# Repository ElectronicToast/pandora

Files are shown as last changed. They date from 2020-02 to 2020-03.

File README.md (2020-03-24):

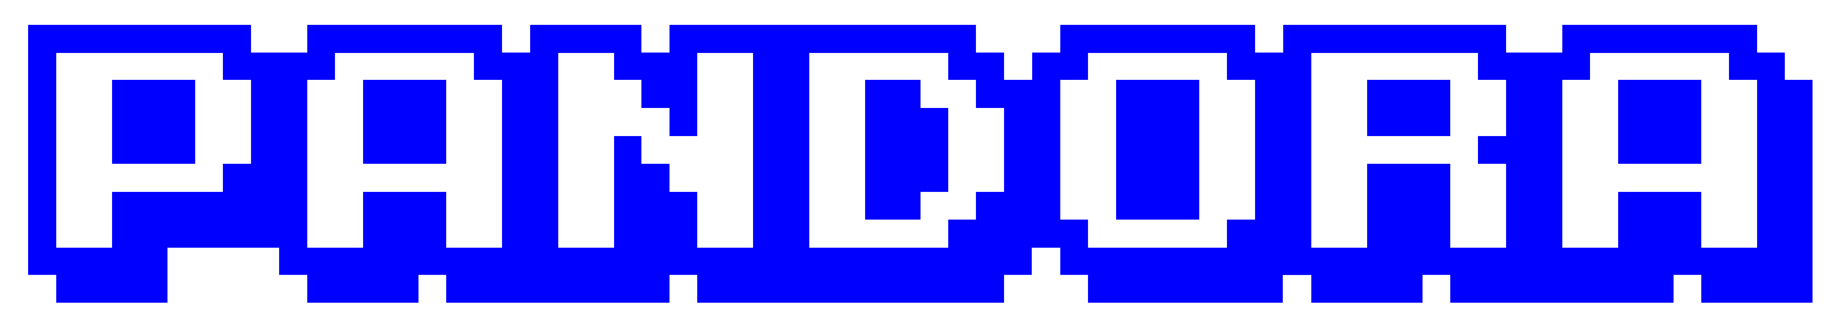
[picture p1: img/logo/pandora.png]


  

TI SimpleLink CC2652R mesh network embedded system development board

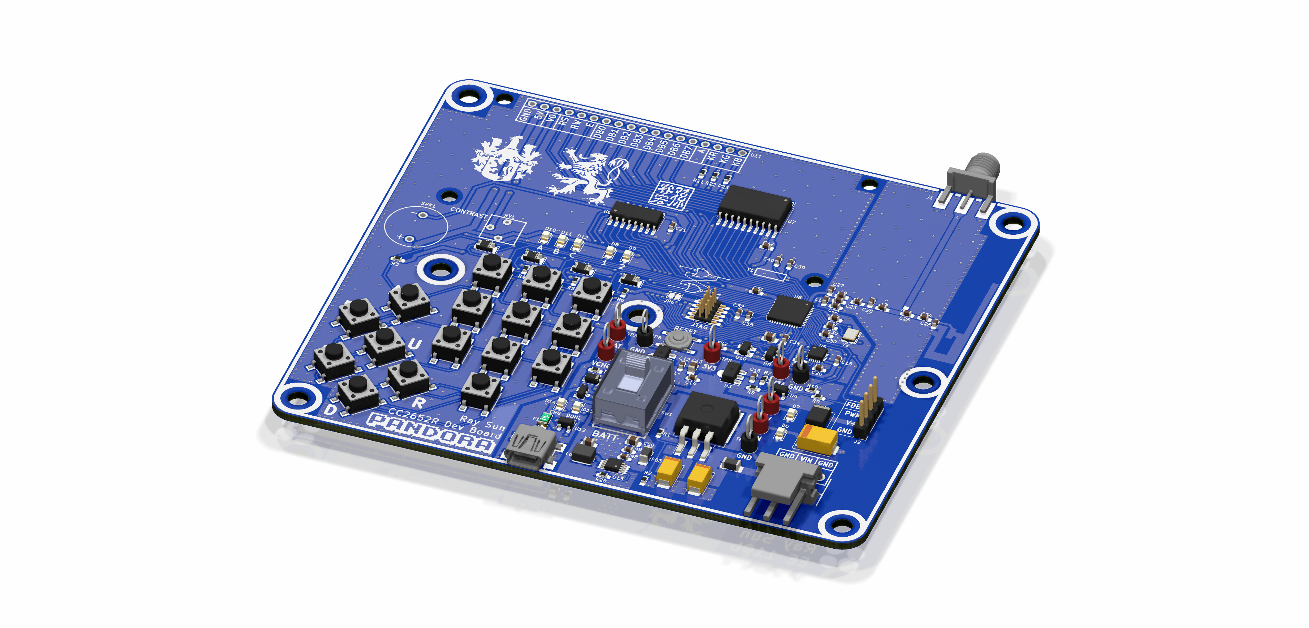
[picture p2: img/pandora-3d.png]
board-3d


## Description
Pandora is a development board for the TI SimpleLink CC2652R multiprotocol dual-core ARM wireless MCU designed for the Embedded System Design Laboratory course at Caltech (EE 110b). The board features interfaces for connecting a servo with analog feedback output and a [16x2 RGB-backlit LCD](https://www.adafruit.com/product/399). An onboard 16-key keypad and MPU-9250 IMU are provided for development use.

Pandora is intended to be powered from either an external 6-8.2V supply or a single-cell 3.7V LiPo battery. The former must be used to power the servo. A slide switch is used to select the power source. An onboard LiPo charger is present for charging through the USB-mini jack.

A TI SWRU120D 2.4GHz inverted-F PCB antenna is provided, in addition to a SMA jack for connecting an external 2.4GHz antenna. The antenna is selected using an 0603 two-way jumper.

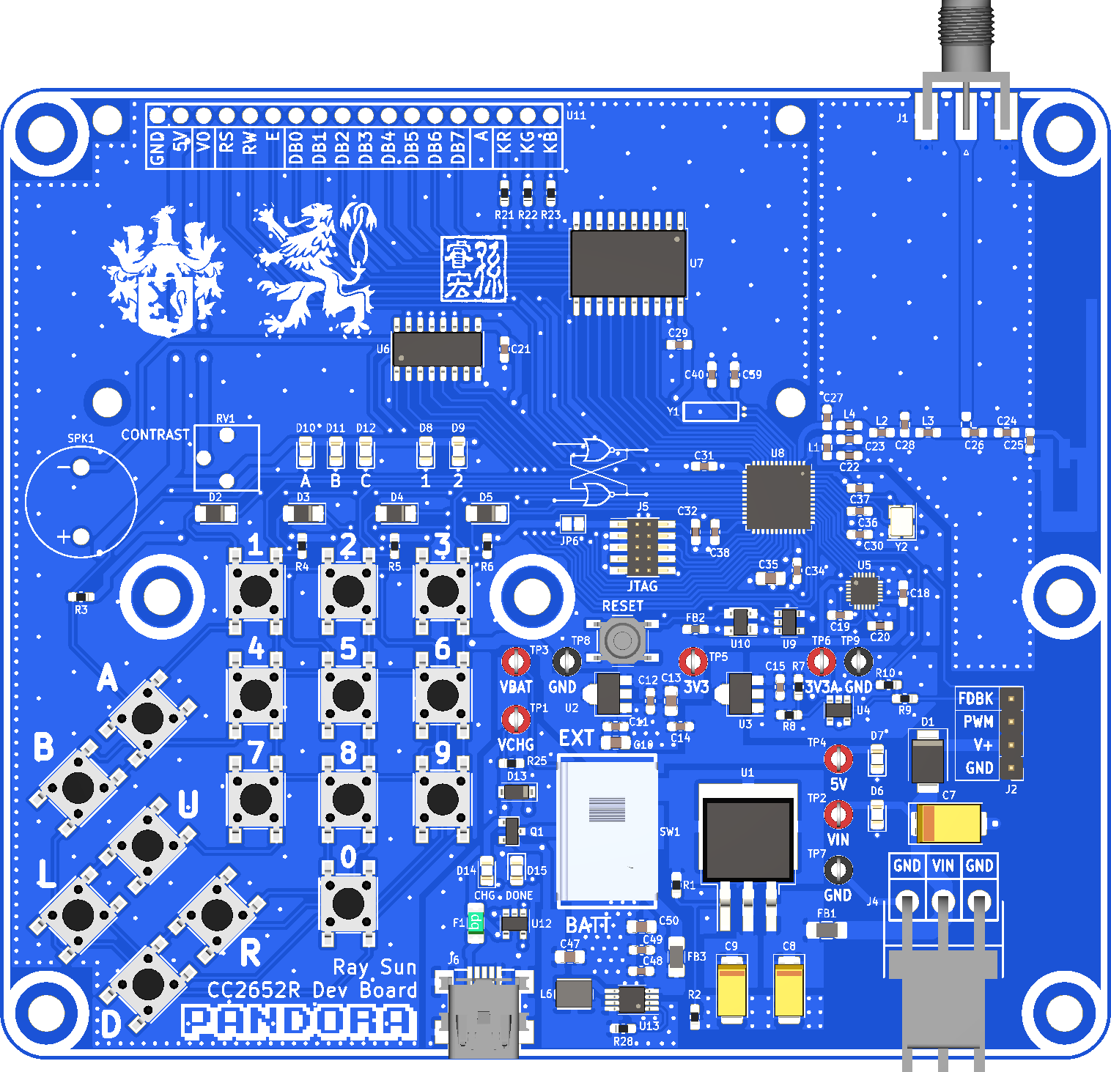
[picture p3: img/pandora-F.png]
board-f

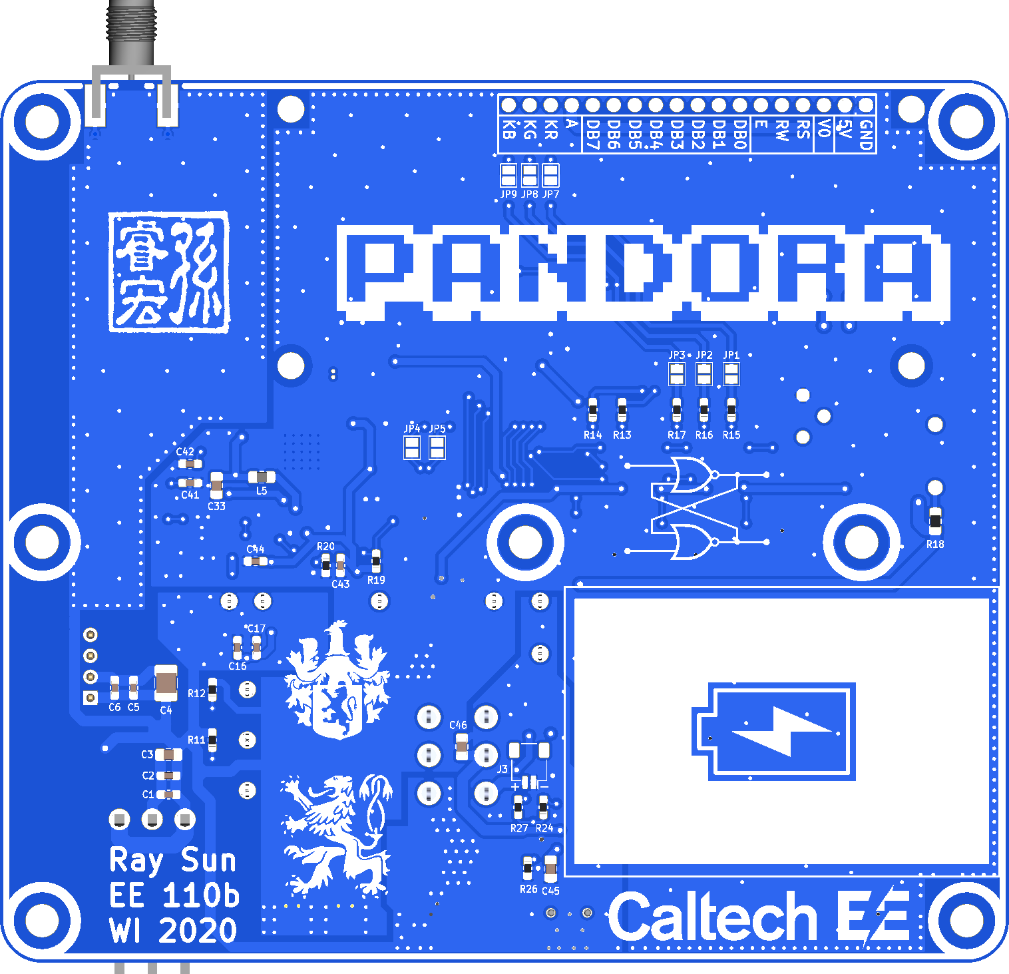
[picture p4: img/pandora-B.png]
board-b


This PCB is designed with KiCad v.5.1.5. Documentation may be found under `/doc`, and Gerbers under `/gerber`. 

## Author
- Ray Sun - Undergraduate, Electrical Engineering, Caltech, Class of 2020

## Licensing
This project is released under the terms of the MIT License. The SWRU120D antenna design is copyright 2007–2019, Texas Instruments Incorporated, and is used here for development of an application that uses a TI SimpleLink wireless microcontroller.

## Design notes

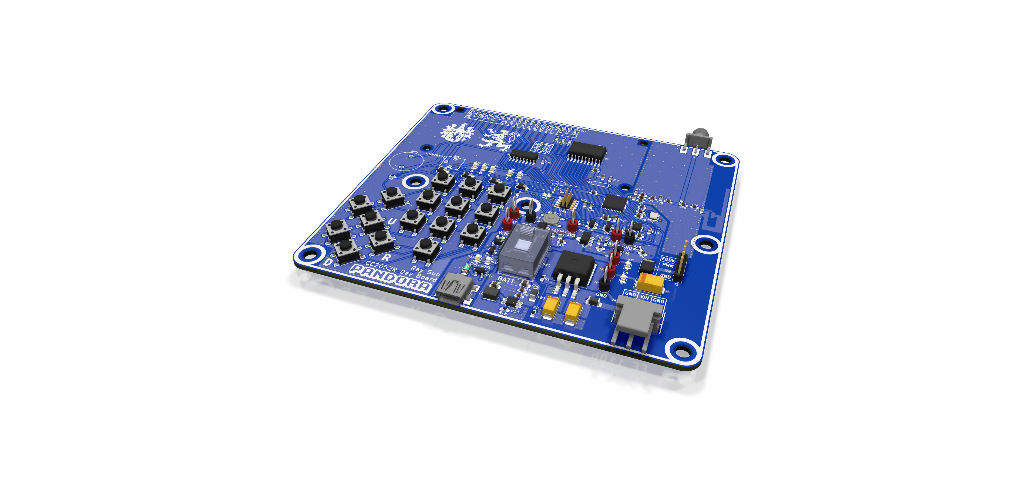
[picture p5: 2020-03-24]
img/pandora-3d-proj.png

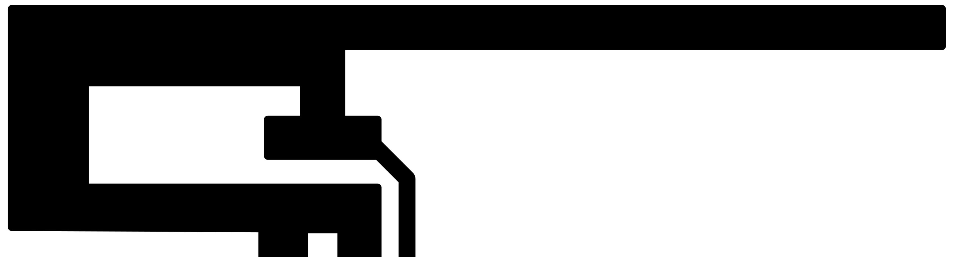
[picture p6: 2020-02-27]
img/footprints/SWRU120D.png

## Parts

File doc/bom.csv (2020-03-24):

Designator | Value | FootprintRef | Datasheet | Comment | Footprint | PartNo | Supplier | SupplierPartNo | Qty
AE1 | SWRU120D | pandora:Texas_SWRU120D_InvF_2.4GHz_Left | http://www.ti.com/lit/an/swru120d/swru120d.pdf | PCB antenna | SWRU120D | N/A | N/A | N/A | 1
> C1, C6, C16, C19-C21, C29-C32, C34, C36, C37, C43, C44, C48 | 0.1uF | Capacitor_SMD:C_0603_1608Metric_Pad1.05x0.95mm_HandSolder | ~ |  | 603 |  | In House | N/A | 16
C4 | 47uF | Capacitor_SMD:C_1210_3225Metric_Pad1.42x2.65mm_HandSolder | ~ |  | 805 |  | In House | N/A | 1
C7 | 47uF | Capacitor_Tantalum_SMD:CP_EIA-7343-31_Kemet-D | https://content.kemet.com/datasheets/KEM_T2005_T491.pdf | 25V | 2917 | T491D476M025AT | Digi-Key | 399-3797-1-ND | 1
> C8, C9 | 10uF | Capacitor_Tantalum_SMD:CP_EIA-6032-28_Kemet-C_Pad2.25x2.35mm_HandSolder | http://datasheets.avx.com/trj.pdf | 35V | 2312 | TRJC106K035R0600 | Digi-Key | 478-7582-1-ND | 2
> C10, C33, C35 | 22uF | Capacitor_SMD:C_0805_2012Metric_Pad1.15x1.40mm_HandSolder | ~ |  | 805 |  | In House | N/A | 3
> C2, C5, C11, C12, C14, C15, C17, C38, C49 | 1uF | Capacitor_SMD:C_0603_1608Metric_Pad1.05x0.95mm_HandSolder | ~ |  | 603 |  | In House | N/A | 9
> C3, C13, C50 | 10uF | Capacitor_SMD:C_0805_2012Metric_Pad1.15x1.40mm_HandSolder | ~ |  | 805 |  | In House | N/A | 3
C18 | 10nF | Capacitor_SMD:C_0603_1608Metric_Pad1.05x0.95mm_HandSolder | ~ |  | 603 |  | In House | N/A | 1
C22 | 12pF | pandora:0603 | ~ |  | 603 |  | In House | N/A | 1
C24 | 1.8pF | pandora:0603 | ~ |  | 603 |  | In House | N/A | 1
C25 | DNP | pandora:0603 | ~ |  | 603 |  | In House | N/A | 1
C26 | 12pF | pandora:0603_Branch | ~ |  | 0603-2way |  | In House | N/A | 1
> C23, C27, C28 | 1pF | pandora:0603 | ~ |  | 603 |  | In House | N/A | 3
> C39, C40 | 15pF | Capacitor_SMD:C_0603_1608Metric_Pad1.05x0.95mm_HandSolder | ~ |  | 603 |  | In House | N/A | 2
> C41, C42 | 12pF | Capacitor_SMD:C_0603_1608Metric_Pad1.05x0.95mm_HandSolder | ~ |  | 603 |  | In House | N/A | 2
> C45-C47 | 4.7uF | Capacitor_SMD:C_0805_2012Metric_Pad1.15x1.40mm_HandSolder | ~ |  | 805 |  | In House | N/A | 3
D1 | S3JBHR5G | Diode_SMD:D_SMB | https://www.onsemi.com/pub/Collateral/1N5400-D.PDF | 3A | SMB | S3JBHR5G | Digi-Key | S3JBHR5GCT-ND | 1
> D2-D5 | 1N4148 | Diode_SMD:D_1206_3216Metric_Pad1.42x1.75mm_HandSolder | https://www.diodes.com/assets/Datasheets/ds30086.pdf |  | 1206 / SOD-123 |  | In House | N/A | 4
> D6, D10 | RED | LED_SMD:LED_0805_2012Metric_Pad1.15x1.40mm_HandSolder | ~ |  | 805 |  | In House | N/A | 2
> D7, D11, D15 | GREEN | LED_SMD:LED_0805_2012Metric_Pad1.15x1.40mm_HandSolder | ~ |  | 805 |  | In House | N/A | 3
> D8, D9, D12 | BLUE | LED_SMD:LED_0805_2012Metric_Pad1.15x1.40mm_HandSolder | ~ |  | 805 |  | In House | N/A | 3
D13 | PMEG10020ELRX | pandora:D_SOD-123W | https://assets.nexperia.com/documents/data-sheet/PMEG10020ELR.pdf |  | SOD-123W | PMEG10020ELRX | Digi-Key | 1727-2396-1-ND | 1
D14 | ORANGE | LED_SMD:LED_0805_2012Metric_Pad1.15x1.40mm_HandSolder | ~ |  | 805 |  | In House | N/A | 1
F1 | 0ZCJ0075FF2E | Fuse:Fuse_1206_3216Metric_Pad1.42x1.75mm_HandSolder | https://www.belfuse.com/resources/datasheets/circuitprotection/ds-cp-0zcj-series.pdf | Charging input fuse, 750mA hold | 1206 | 0ZCJ0075FF2E | Digi-Key | 507-1804-1-ND | 1
> FB1, FB3 | 1206_4A | Inductor_SMD:L_1206_3216Metric_Pad1.42x1.75mm_HandSolder | https://ds.yuden.co.jp/TYCOMPAS/ut/detail?pn=BKP2125HS600-T%20%20&u=M |  | 1206 | FBMJ3216HS800-T | Digi-Key | 587-1772-1-ND | 2
FB2 | 0603_500mA | Inductor_SMD:L_0603_1608Metric_Pad1.05x0.95mm_HandSolder | https://ds.yuden.co.jp/TYCOMPAS/ut/detail?pn=BKP1608HS391-T%20%20&u=M |  | 603 | BKP1608HS391-T | Digi-Key | 587-1927-1-ND | 1
> H1-H7 | #6 | pandora:MountingHole_No6 | ~ | #6 mounting hole, NPTH | HOLE_156mil_NPTH | N/A | N/A | N/A | 7
J1 | SMA | Connector_Coaxial:SMA_Molex_73251-1153_EdgeMount_Horizontal | https://www.molex.com/pdm_docs/sd/732511153_sd.pdf | External antenna connector | SMA_SMD_RightAngle | 732511150 | Molex | 732511150 | 1
J2 | PinHeader_100mil_01x04 | Connector_PinHeader_2.54mm:PinHeader_1x04_P2.54mm_Vertical | ~ | Servo connector | 100mil_01x04 |  | In House | N/A | 1
J3 | JST-SH_2 | Connector_JST:JST_SH_SM02B-SRSS-TB_1x02-1MP_P1.00mm_Horizontal | ~ | JST SH auxiliary Li-ion connector | JST-SH_SM_2_SMD_RghtAngle |  | In House | N/A | 1
J4 | TX3 / MTA-156-3 | pandora:TE_640389-3 | ~ | 156mil 3-pin power connector | 156mil_01x03 |  | In House | N/A | 1
J5 | Conn_ARM_JTAG_SWD_10 | pandora:PinHeader_2x05_P1.27mm_Vertical_SMD_Long | http://infocenter.arm.com/help/topic/com.arm.doc.ddi0314h/DDI0314H_coresight_components_trm.pdf | JTAG debug header | 50mil_02x05 | FTSH-105-0.1-F-DV-K | In House | N/A | 1
J6 | USB_B_Mini | pandora:USB_MiniB_KMBSMT5SS30 | ~ | 5V battery charge connector | KMBSMT5SS30 | KMBSMT5SS30 | In House | N/A | 1
> JP1-JP5, JP7-JP9 | SJ2 | Jumper:SolderJumper-2_P1.3mm_Open_Pad1.0x1.5mm | ~ | Solder jumper, 2 pad | SMD_PAD_SJ2 | N/A | N/A | N/A | 8
JP6 | SJ2_Bridged | Jumper:SolderJumper-2_P1.3mm_Bridged_Pad1.0x1.5mm | ~ | Solder jumper, 2 pad, bridged | SMD_PAD_SJ2_Bridged | N/A | N/A | N/A | 1
> L2, L3 | 2nH | pandora:0603 | ~ |  | 603 |  | In House | N/A | 2
> L1, L4 | 2.4nH | pandora:0603 | ~ |  | 603 |  | In House | N/A | 2
L5 | 6.8uH | Inductor_SMD:L_0805_2012Metric_Pad1.15x1.40mm_HandSolder | https://product.tdk.com/info/en/catalog/datasheets/inductor_automotive_decoupling_mlz2012_en.pdf | MCU analog filter inductor | 805 | MLZ2012N6R8LTD25 | Digi-Key | 445-16384-1-ND | 1
L6 | 4.7uH | Inductor_SMD:L_Wuerth_MAPI-4020 | https://www.we-online.com/catalog/datasheet/74438356047.pdf | Power inductor for boost converter | Wuerth_MAPI-4020 | 74438356047 | Digi-Key | 732-8234-1-ND | 1
> NT1-NT5 | Net-Tie_2 | pandora:NetTie-2_SMD_50mil | ~ |  | N/A | N/A | N/A | N/A | 5
Q1 | DMP1045U | Package_TO_SOT_SMD:SOT-23 | https://www.diodes.com/assets/Datasheets/DMP1045U.pdf | Load sharing P-MOSFET | SOT-23 | DMP1045U-7 | Digi-Key | DMP1045U-7DICT-ND | 1
> R1, R12 | 1.2k | Resistor_SMD:R_0603_1608Metric_Pad1.05x0.95mm_HandSolder | ~ |  | 603 |  | In House | N/A | 2
R2 | 3.6k | Resistor_SMD:R_0603_1608Metric_Pad1.05x0.95mm_HandSolder | ~ |  | 603 |  | In House | N/A | 1
> R3-R6, R19, R25, R26, R28 | 10k | Resistor_SMD:R_0603_1608Metric_Pad1.05x0.95mm_HandSolder | ~ |  | 603 |  | In House | N/A | 8
R8 | 160k | Resistor_SMD:R_0603_1608Metric_Pad1.05x0.95mm_HandSolder | ~ |  | 603 |  | In House | N/A | 1
> R7, R9 | 150k | Resistor_SMD:R_0603_1608Metric_Pad1.05x0.95mm_HandSolder | ~ |  | 603 |  | In House | N/A | 2
R10 | 120k | Resistor_SMD:R_0603_1608Metric_Pad1.05x0.95mm_HandSolder | ~ |  | 603 |  | In House | N/A | 1
R11 | 3.3k | Resistor_SMD:R_0603_1608Metric_Pad1.05x0.95mm_HandSolder | ~ |  | 603 |  | In House | N/A | 1
R13 | 330 | Resistor_SMD:R_0603_1608Metric_Pad1.05x0.95mm_HandSolder | ~ |  | 603 |  | In House | N/A | 1
> R14, R17 | 390 | Resistor_SMD:R_0603_1608Metric_Pad1.05x0.95mm_HandSolder | ~ |  | 603 |  | In House | N/A | 2
R15 | 680 | Resistor_SMD:R_0603_1608Metric_Pad1.05x0.95mm_HandSolder | ~ |  | 603 |  | In House | N/A | 1
R16 | 560 | Resistor_SMD:R_0603_1608Metric_Pad1.05x0.95mm_HandSolder | ~ |  | 603 |  | In House | N/A | 1
R18 | 10 | Resistor_SMD:R_0805_2012Metric_Pad1.15x1.40mm_HandSolder | ~ | Speaker power resistor | 805 |  | In House | N/A | 1
R20 | 100k | Resistor_SMD:R_0603_1608Metric_Pad1.05x0.95mm_HandSolder | ~ |  | 603 |  | In House | N/A | 1
> R21-R23 | 0 | Resistor_SMD:R_0603_1608Metric_Pad1.05x0.95mm_HandSolder | ~ |  | 603 |  | In House | N/A | 3
> R24, R27 | 1k | Resistor_SMD:R_0603_1608Metric_Pad1.05x0.95mm_HandSolder | ~ |  | 603 |  | In House | N/A | 2
RV1 | 10k | pandora:Pot_VR4_Small | https://www.bourns.com/docs/Product-Datasheets/TC33.pdf | LCD contrast potentiometer | Bourns_TC33 | TC33X-2-103E | Digi-Key | TC33X-103ECT-ND | 1
SPK1 | DBX-01PN | pandora:DBX-01PN | ~ | Speaker, board mount | DBX-01PN | DBX-01PN | In House | DBX-01PN | 1
SW1 | GF-126-0317 | pandora:GF-126-0317 | https://media.digikey.com/pdf/Data%20Sheets/CW%20Industries%20PDFs/GF-126-0317.pdf | Power switch | GF-126-037 | GF-126-037 | Digi-Key | CWI351-ND | 1
> SW2-SW8, SW10-SW12 | PTS645-S-H-50-SMTR92-LFS | pandora:SW_Push_PTS645_SMT | https://dznh3ojzb2azq.cloudfront.net/products/Tactile/PTS645/documents/datasheet.pdf | Keypad button, black | Tact_Push_SMD_6mm | PTS645SH50SMTR92 LFS | Digi-Key | CKN9085CT-ND | 10
> SW9, SW13 | PTS645-S-M-43-SMTR92-LFS | pandora:SW_Push_PTS645_SMT | https://dznh3ojzb2azq.cloudfront.net/products/Tactile/PTS645/documents/datasheet.pdf | Keypad button, blue | Tact_Push_SMD_6mm | PTS645SM43SMTR92 LFS | Digi-Key | CKN9112CT-ND | 2
> SW14-SW17 | PTS645-S-K-50-SMTR92-LFS | pandora:SW_Push_PTS645_SMT | https://dznh3ojzb2azq.cloudfront.net/products/Tactile/PTS645/documents/datasheet.pdf | Keypad button, red | Tact_Push_SMD_6mm | PTS645SK50SMTR92 LFS | Digi-Key | CKN9087CT-ND | 4
SW18 | PTS526-S-K-15-SMTR92 | pandora:SW_Push_PTS526 | https://dznh3ojzb2azq.cloudfront.net/products/Tactile/PTS526/documents/datasheet.pdf | Reset button | Tact_Push_SMD_PTS526 | PTS526SK15SMTR92 LFS | In House | PTS526SK15SMTR92 LFS | 1
> TP1-TP9 | TestPoint | pandora:TestPoint_62-80mil | ~ | Test point | Hole_62mil | TP | In House | TP | 9
U1 | LM1086CS-ADJ | Package_TO_SOT_SMD:TO-263-3_TabPin2 | http://www.ti.com/lit/ds/snvs039j/snvs039j.pdf | 5V LDO | TO-263 | LM1086CS-ADJ | In House | LM1086CS-ADJ | 1
> U2, U3 | MCP1702T-3302 | Package_TO_SOT_SMD:SOT-89-3 | http://ww1.microchip.com/downloads/en/devicedoc/22008e.pdf | ... | SOT-89-3 | MCP1702T-3302 | In House | MCP1702T-3302 | 2
U4 | MCP6001 | Package_TO_SOT_SMD:SOT-23-5 | http://ww1.microchip.com/downloads/en/DeviceDoc/21733j.pdf | Servo feedback opamp | SOT-23-5 | MCP6001RT-I/OT | In House | MCP6001RT-I/OT | 1
U5 | MPU-9250 | pandora:MPU-9250_Wide | https://store.invensense.com/datasheets/invensense/MPU9250REV1.0.pdf | 9-DOF IMU | QFN-24-EP | MPU-9250 | In House | MPU-9250 | 1
U6 | ULN2003D | Package_SO:SOIC-16_3.9x9.9mm_P1.27mm | http://www.ti.com/lit/ds/symlink/uln2003a.pdf | Peripheral low side switch | SOIC-16 | ULN2003D | In House | ULN2003D | 1
U7 | 74LCX245 | Package_SO:SOIC-20W_7.5x12.8mm_P1.27mm | https://www.mouser.com/datasheet/2/149/74LCX245-21038.pdf | LCD level shifter | SOIC-20W | 74LCX245WM | In House | 74LCX245WM | 1
U8 | CC2652R | pandora:Texas_RGZ0048A_Wide | http://www.ti.com/lit/ds/symlink/cc2652r.pdf | MCU | VQFN-48-EP | CC2652R | In House | CC2652R | 1
U9 | 74LVC1G08 | Package_TO_SOT_SMD:SOT-23-5 | http://www.ti.com/lit/sg/scyt129e/scyt129e.pdf | Auxiliary battery boost converter | SOT-23-5 | SN74LVC1G08DBVR | Digi-Key | 296-11601-1-ND | 1
U10 | ADM811ZARTZ | Package_TO_SOT_SMD:SOT-143 | https://www.analog.com/media/en/technical-documentation/data-sheets/ADM811_812.pdf | Reset supervisor | SOT-143 | ADM811ZARTZ | Analog Devices | ADM811ZARTZ | 1
U11 | LCD_Adafruit_16x02_Neg_RGB | pandora:LCD_Adafruit_16x02_Neg_RGB | https://cdn-shop.adafruit.com/product-files/399/399+spec+sheet.pdf | LCD, negative, LCD backlight | LCD_18 | 399 | In House | Adafruit_399 | 1
U12 | MCP73831-2-OT | Package_TO_SOT_SMD:SOT-23-5 | http://ww1.microchip.com/downloads/en/DeviceDoc/20001984g.pdf | Battery charger | SOT-23-5 | MCP73831-2ACI-OT | Microchip | MCP73831-2ACI-OT | 1
U13 | MCP1642D-50 | pandora:MSOP-8_3x3mm_P0.65mm | http://ww1.microchip.com/downloads/en/DeviceDoc/20005253A.pdf | Auxiliary battery boost converter | MSOP-8 | MCP1642D-50I/MS | Microchip | MCP1642D-50I/MS | 1
Y1 | NC26_32.768k | pandora:NC26H_Mirrored | ~ | Low frequency clock crystal | NC26 | NC26 | In House | NC26 | 1
Y2 | FA-238_48M | Crystal:Crystal_SMD_SeikoEpson_FA238-4Pin_3.2x2.5mm | ~ | High frequency clock crystal | FA-238 | FA-238 | In House | FA-238 | 1

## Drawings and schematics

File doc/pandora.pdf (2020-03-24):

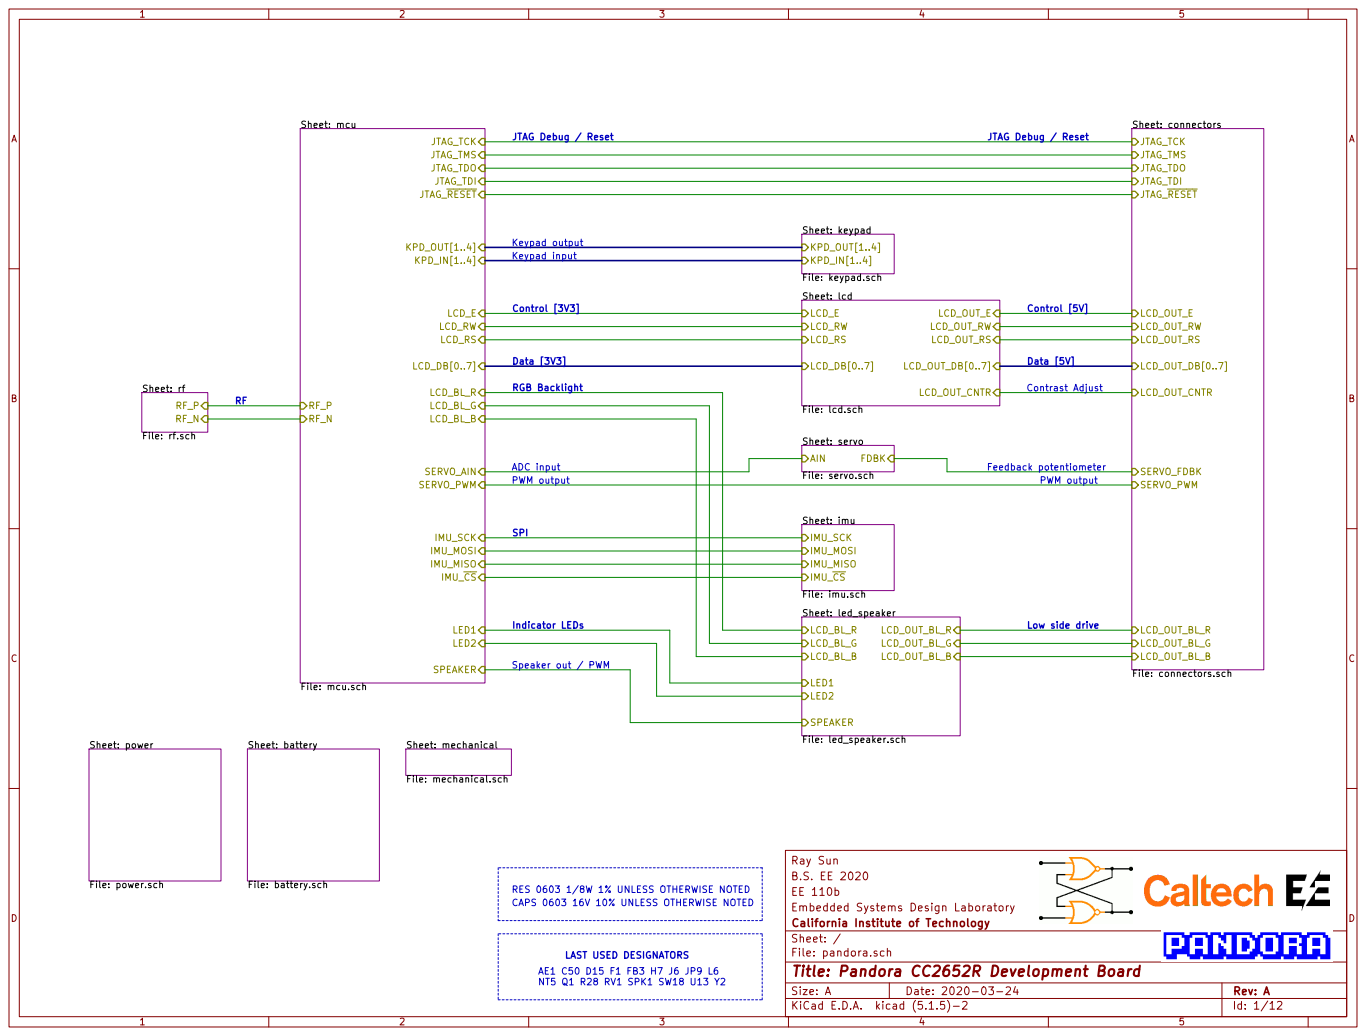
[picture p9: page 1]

Sheet: keypad
KPD_OUT[1..4]
KPD_IN[1..4] Sheet: lcd File: lcd.sch
File: keypad.sch

Feedback potentiometer Low side drive RGB Backlight LAST USED DESIGNATORS

PWM output RES 0603 1/8W 1% UNLESS OTHERWISE NOTED

Embedded Systems Design Laboratory EE 110b B.S. EE 2020 Ray Sun

File: pandora.sch Sheet: / California Institute of Technology

Id: 1/12 Title: Pandora CC2652R Development Board

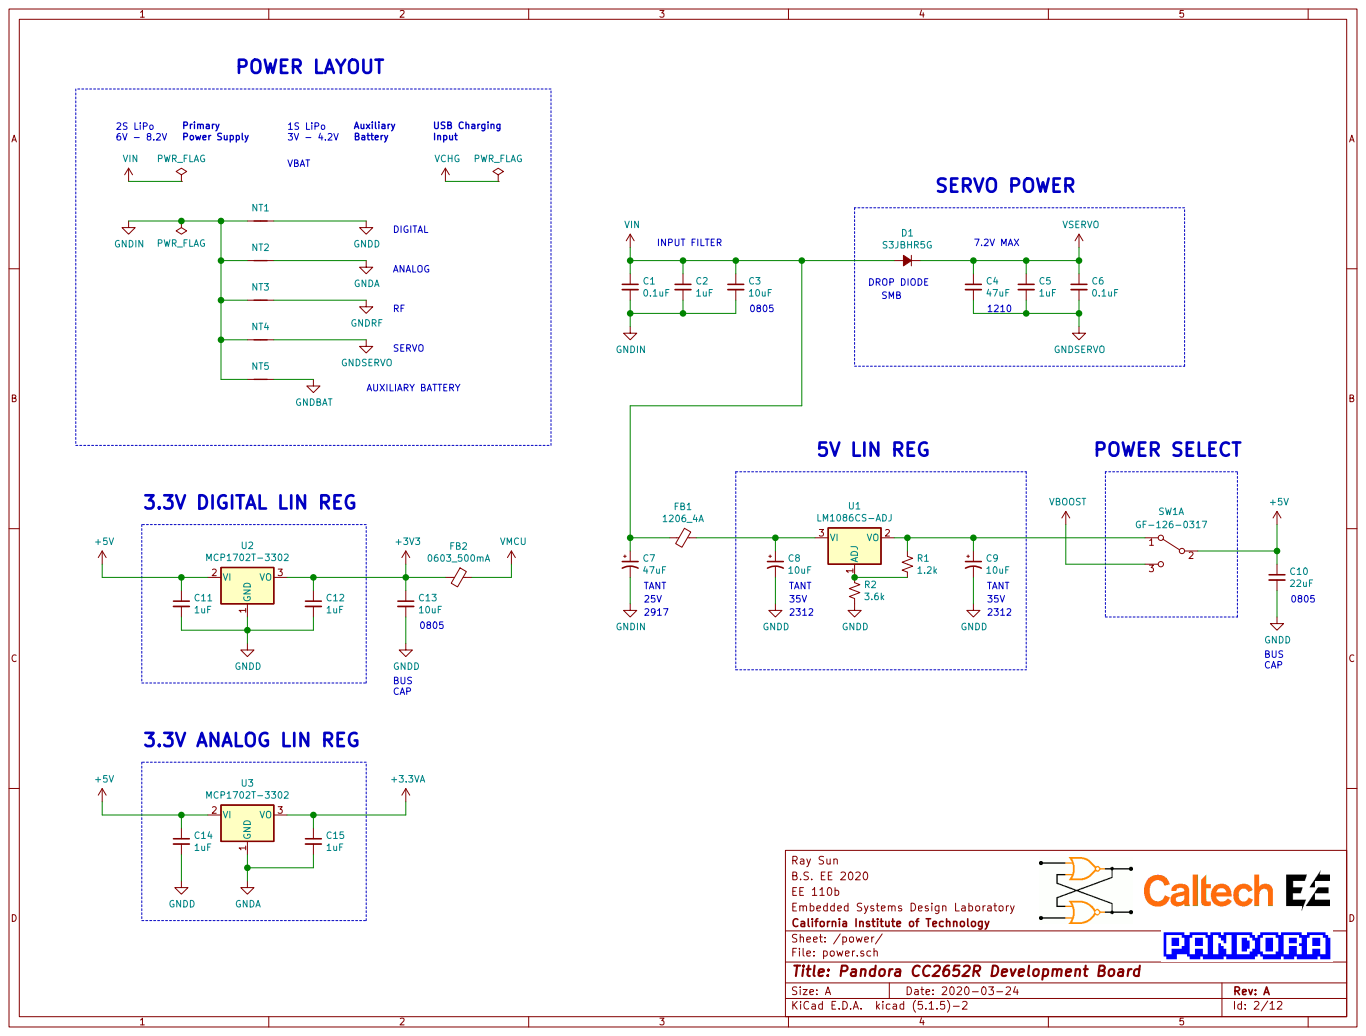
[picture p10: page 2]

INPUT FILTER 3.3V ANALOG LIN REG
PWR_FLAG
DROP DIODE 3.3V DIGITAL LIN REG

California Institute of Technology
Sheet: /power/
File: power.sch
Id: 2/12 Title: Pandora CC2652R Development Board

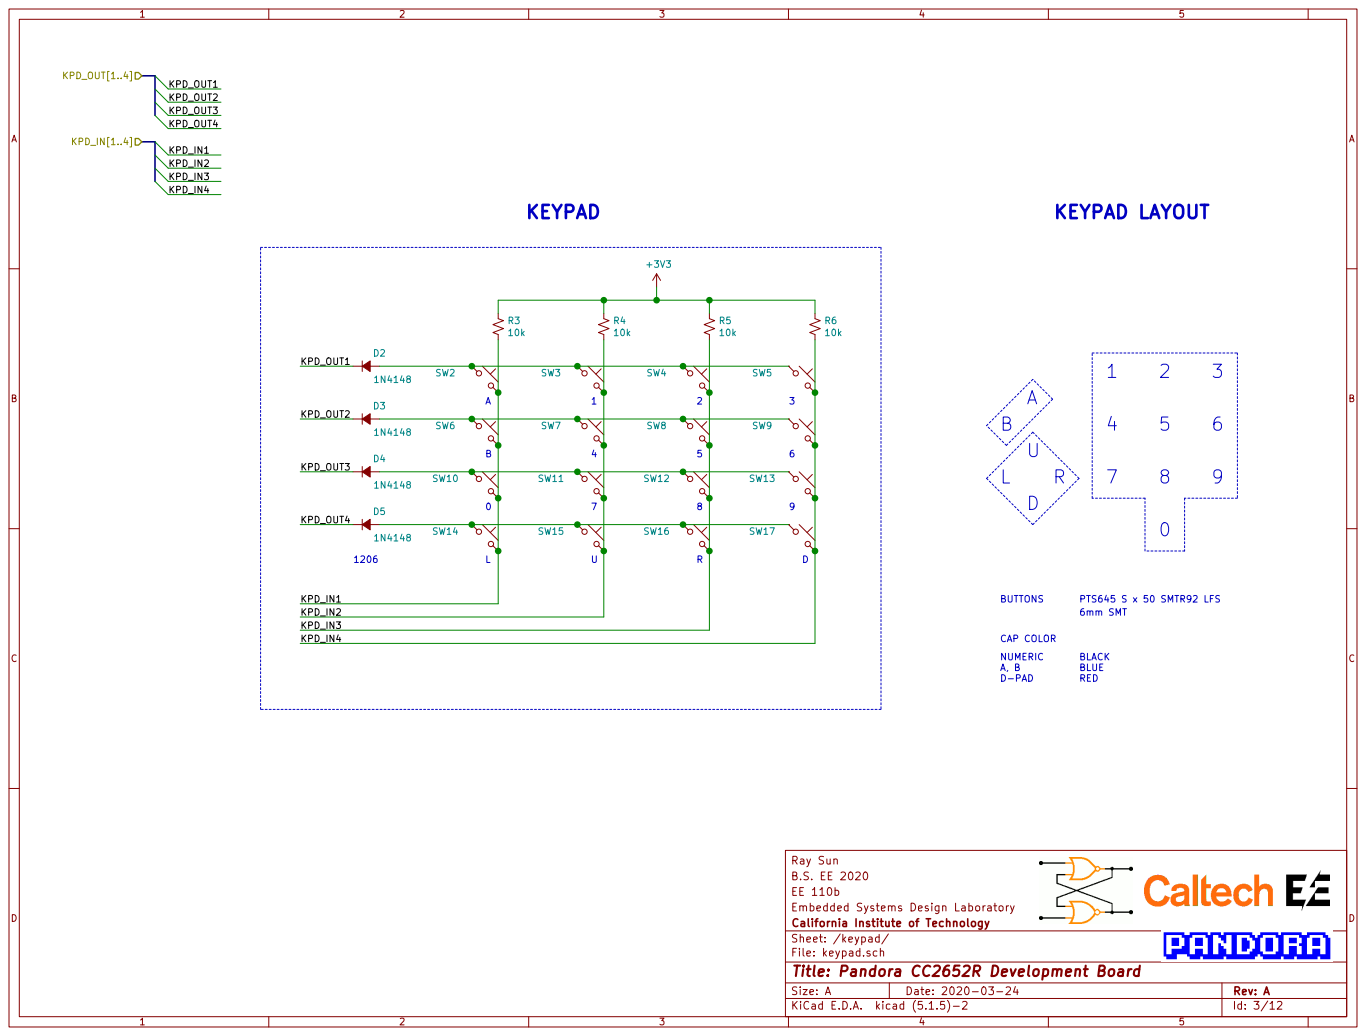
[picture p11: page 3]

Rev: A | D Date: 2020-03-24 KiCad E.D.A. kicad (5.1.5)-2 Size: A
California Institute of Technology

Sheet: /keypad/
File: keypad.sch
Id: 3/12 Title: Pandora CC2652R Development Board

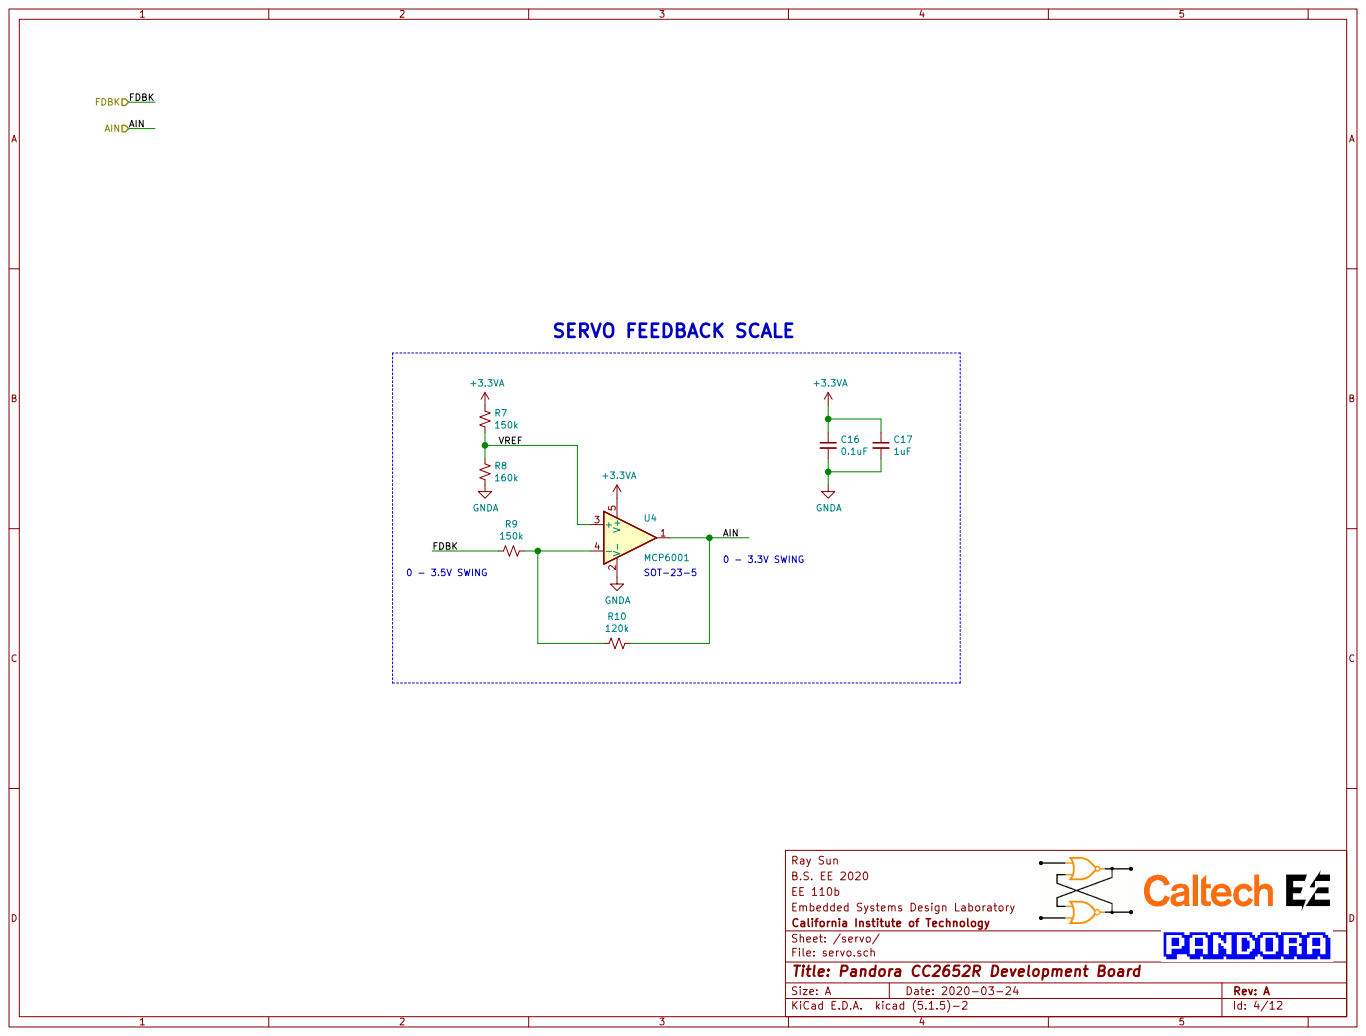
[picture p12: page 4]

0 - 3.3V SWING SERVO FEEDBACK SCALE
160k +3.3VA GNDA

Embedded Systems Design Laboratory EE 110b B.S. EE 2020 Ray Sun GNDA R7
VREF

File: servo.sch Sheet: /servo/ California Institute of Technology

Id: 4/12 Title: Pandora CC2652R Development Board

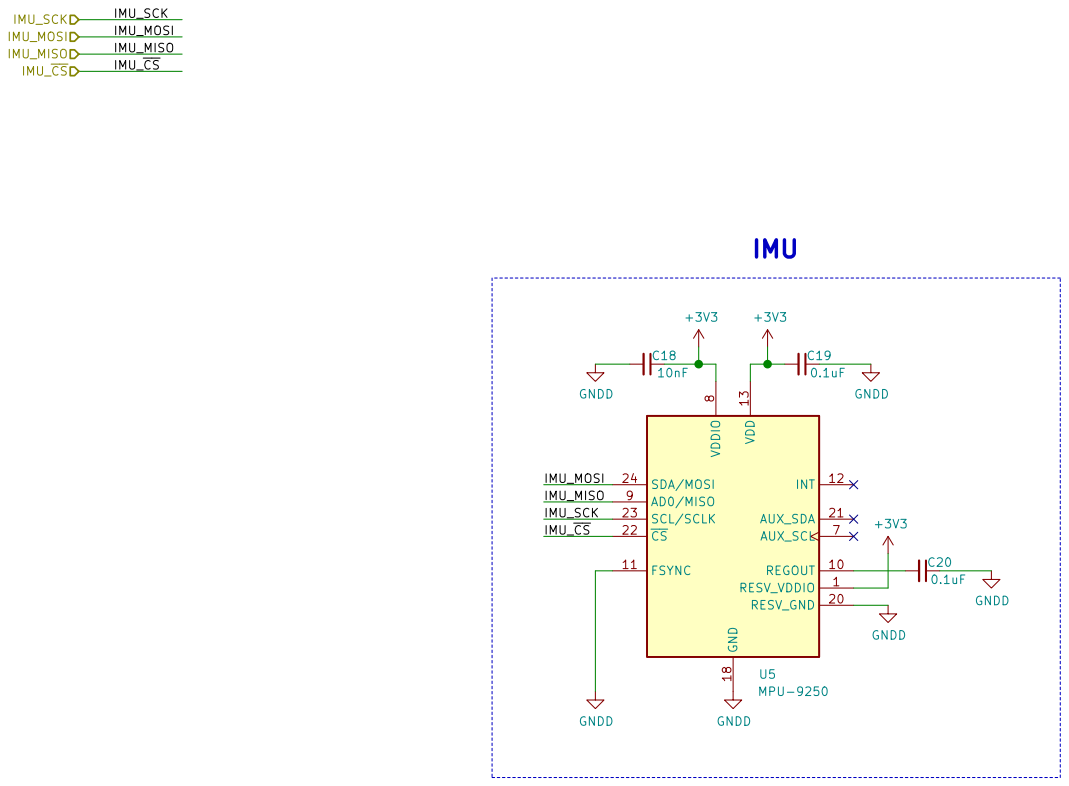
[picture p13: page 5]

Embedded Systems Design Laboratory EE 110b B.S. EE 2020 Ray Sun

File: imu.sch Sheet: /imu/ California Institute of Technology

Id: 5/12 Title: Pandora CC2652R Development Board

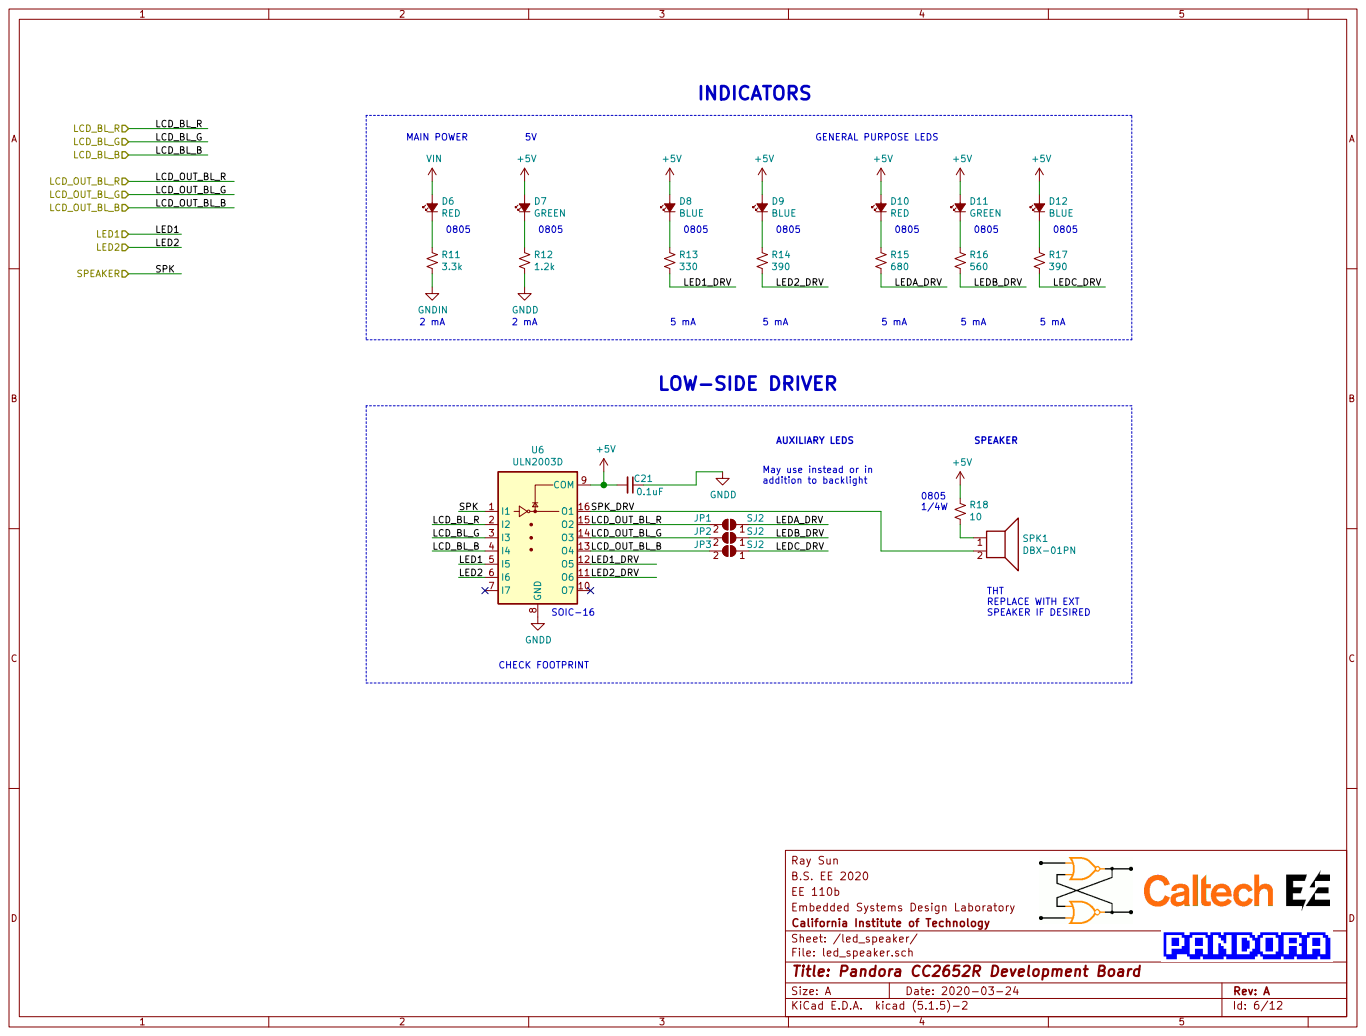
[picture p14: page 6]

Embedded Systems Design Laboratory EE 110b B.S. EE 2020 Ray Sun California Institute of Technology

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

Sheet: /led_speaker/
File: led_speaker.sch
Id: 6/12 Title: Pandora CC2652R Development Board

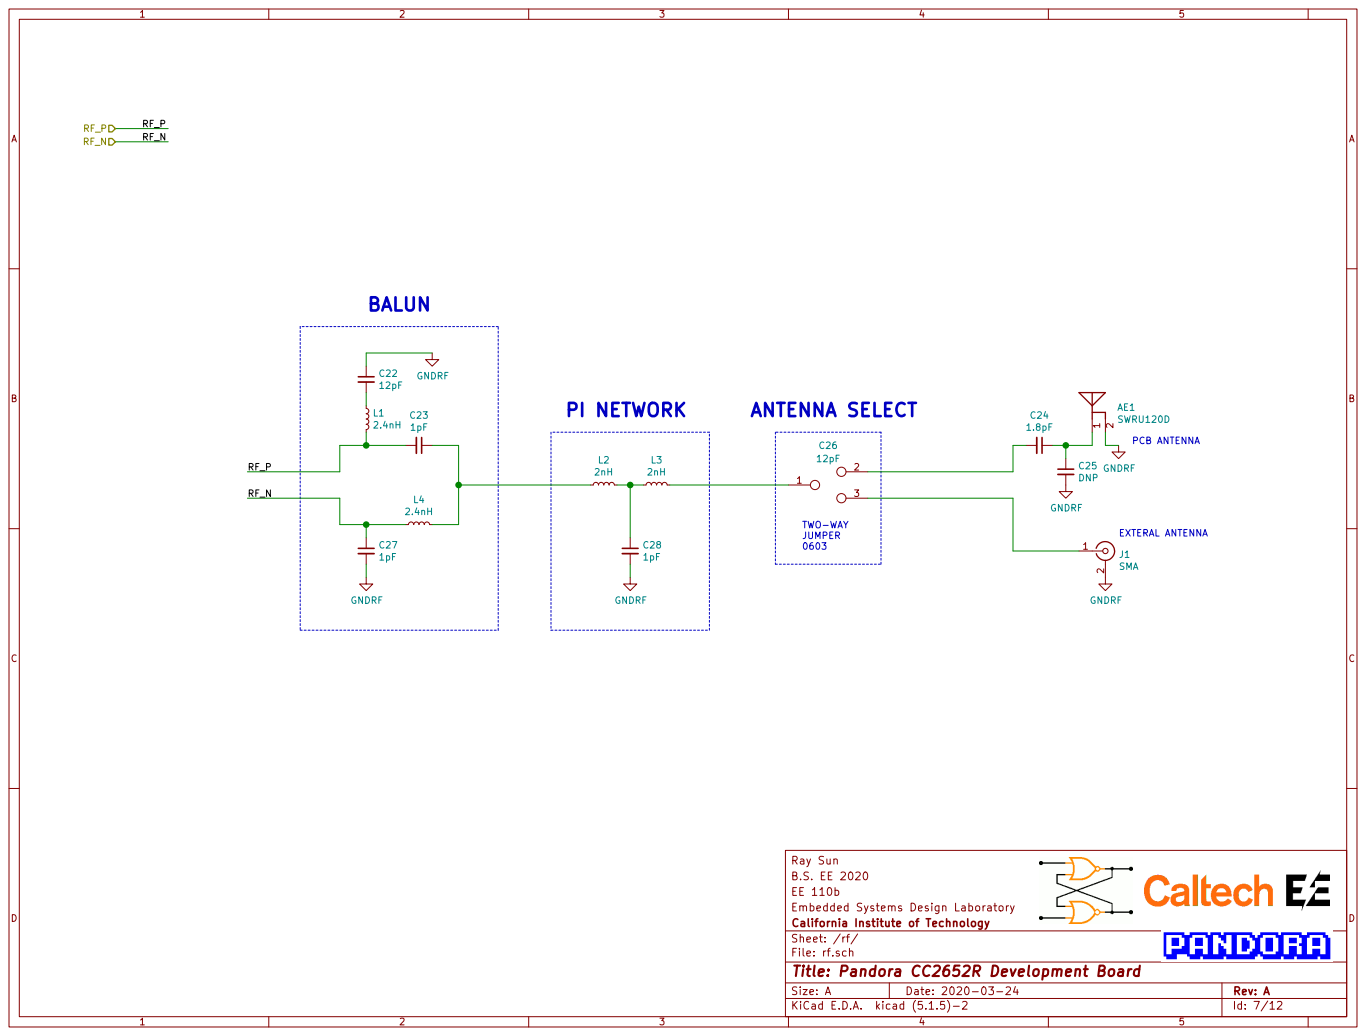
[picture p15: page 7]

PCB ANTENNA PI NETWORK

File: rf.sch Sheet: /rf/ California Institute of Technology

Id: 7/12 Title: Pandora CC2652R Development Board

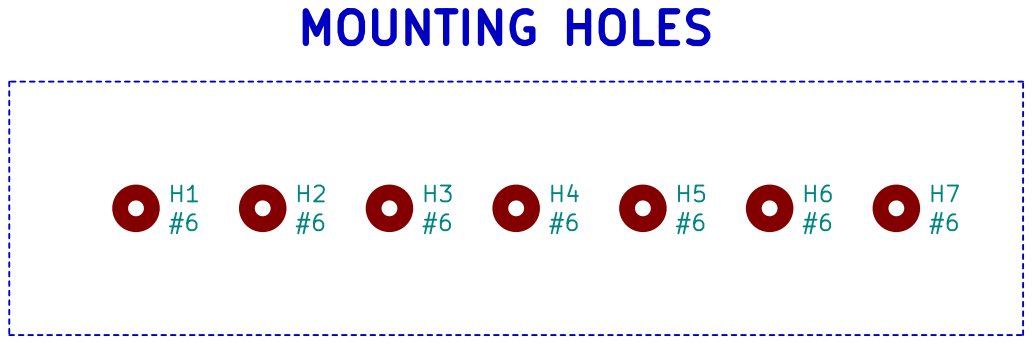
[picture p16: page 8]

Embedded Systems Design Laboratory EE 110b B.S. EE 2020 Ray Sun H1

File: mechanical.sch Sheet: /mechanical/ California Institute of Technology

Id: 8/12 Title: Pandora CC2652R Development Board

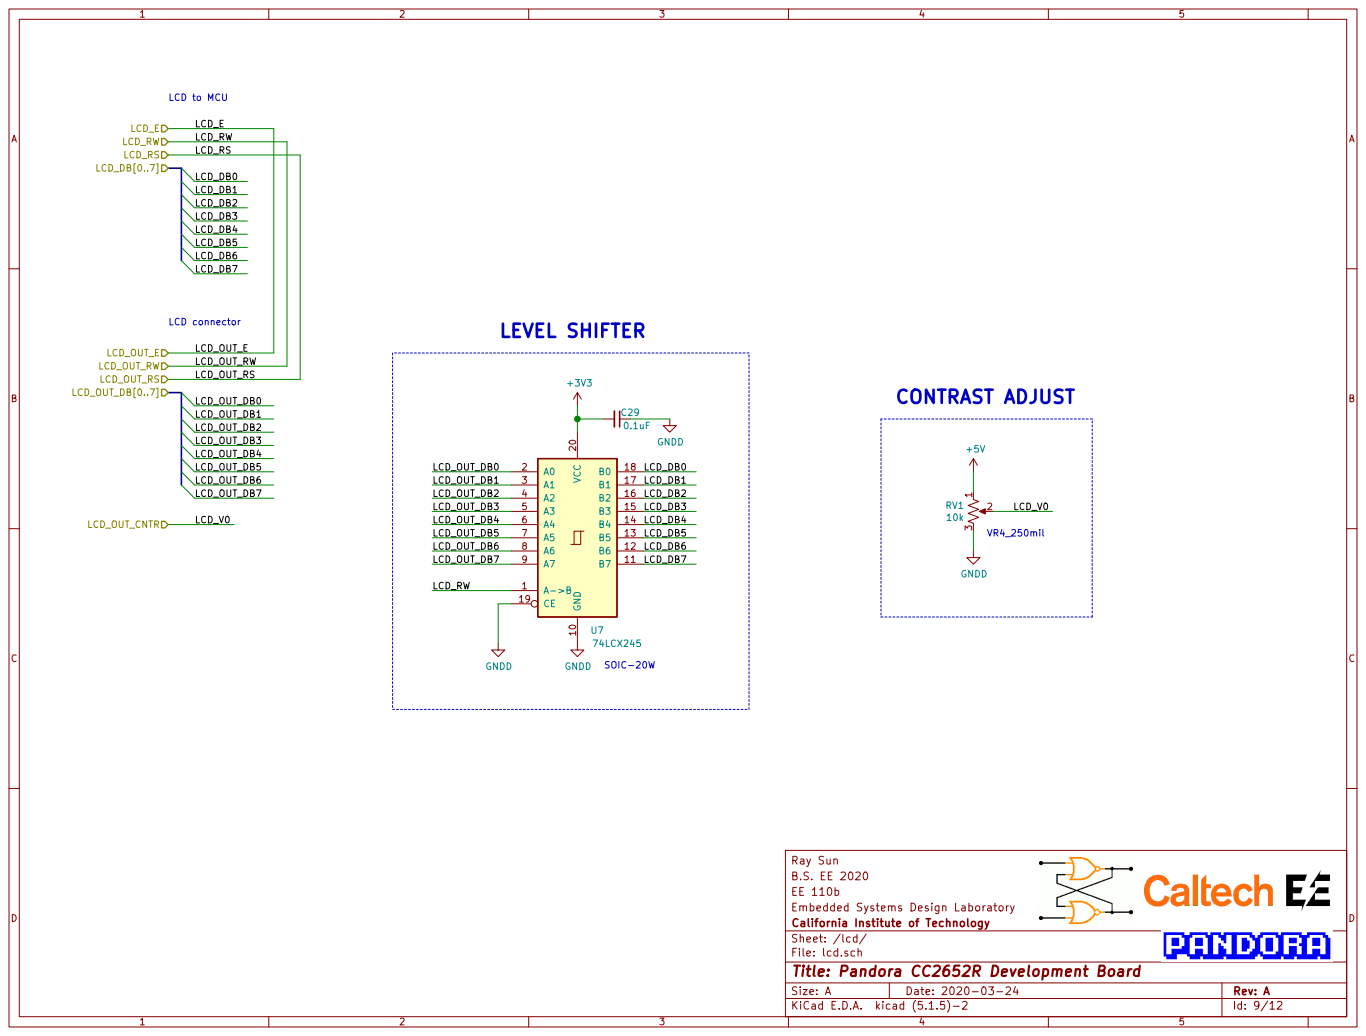
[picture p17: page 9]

Embedded Systems Design Laboratory EE 110b B.S. EE 2020 Ray Sun

File: lcd.sch Sheet: /lcd/ California Institute of Technology

Id: 9/12 Title: Pandora CC2652R Development Board

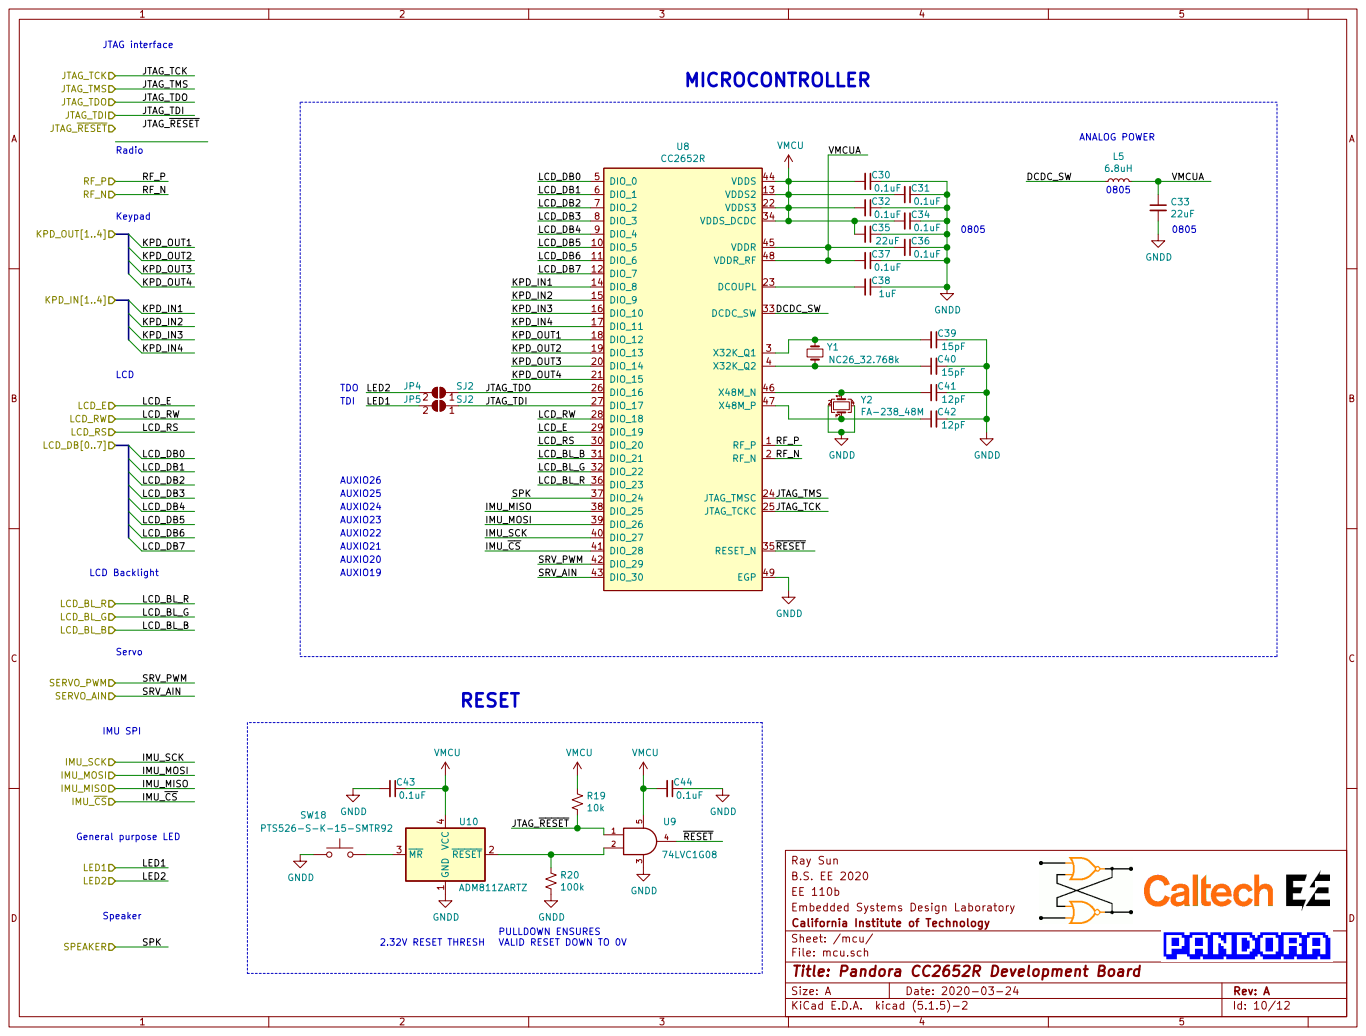
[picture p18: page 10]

Embedded Systems Design Laboratory EE 110b B.S. EE 2020 Ray Sun C44

VALID RESET DOWN TO 0V General purpose LED

File: mcu.sch Sheet: /mcu/ California Institute of Technology

Id: 10/12 Title: Pandora CC2652R Development Board

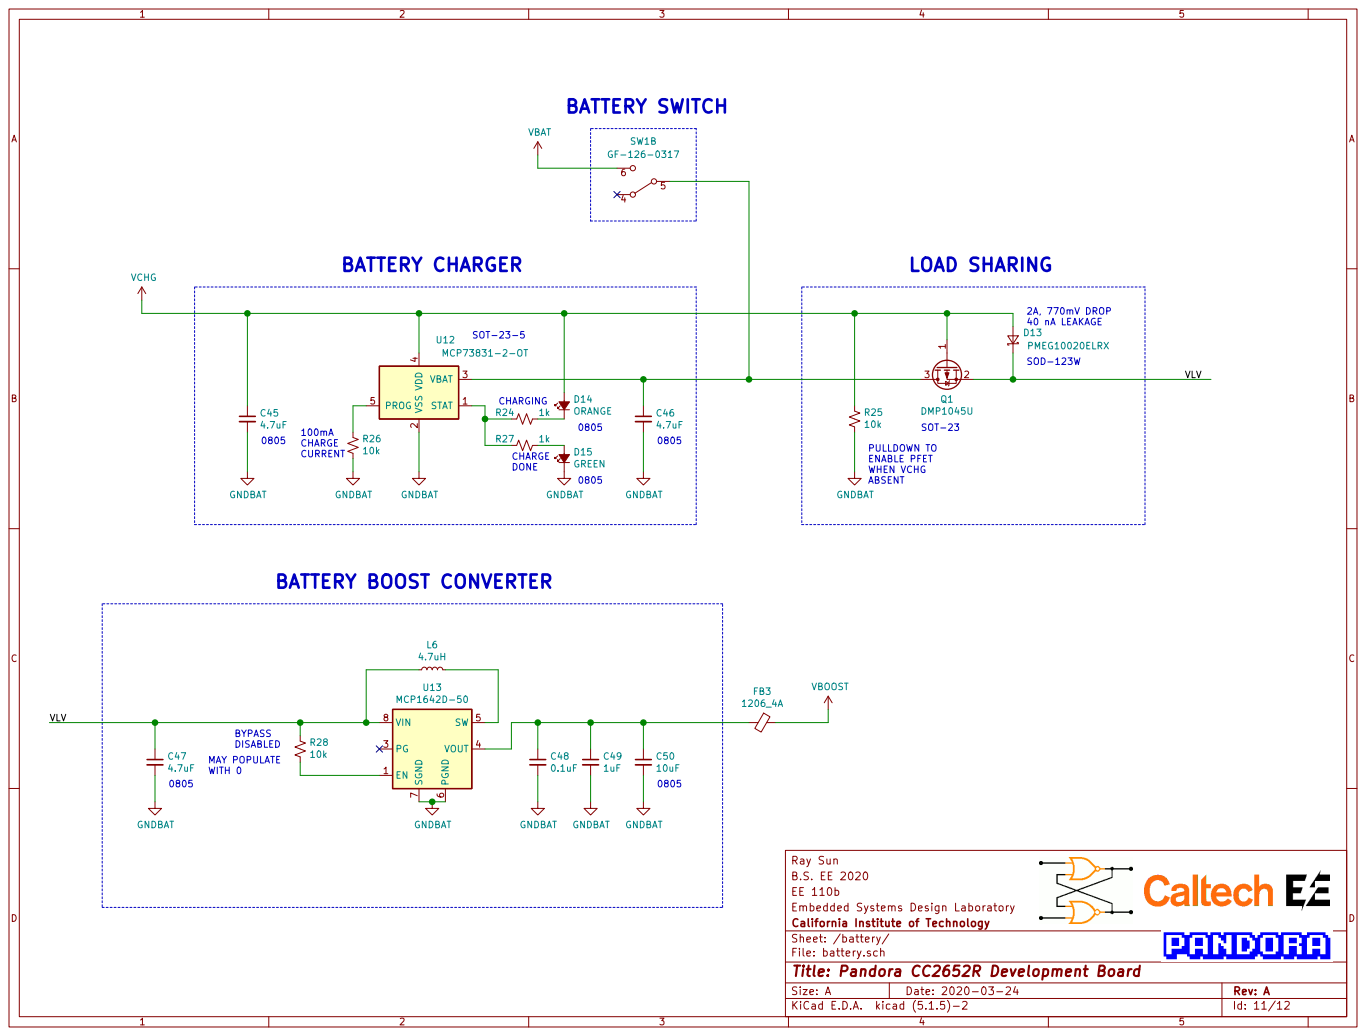
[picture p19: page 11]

4 PROG 5 U12MCP73831-2-OT GNDBAT GNDBAT EN 1 PG 3 VOUT 4 SW 5 PGND

SOT-23 CHARGE DONE CHARGING

PULLDOWN TO
ENABLE PFET WHEN VCHG

MAY POPULATE WITH 0BYPASS DISABLED

Embedded Systems Design Laboratory EE 110b B.S. EE 2020 Ray Sun

California Institute of Technology
Sheet: /battery/
File: battery.sch
Id: 11/12 Title: Pandora CC2652R Development Board

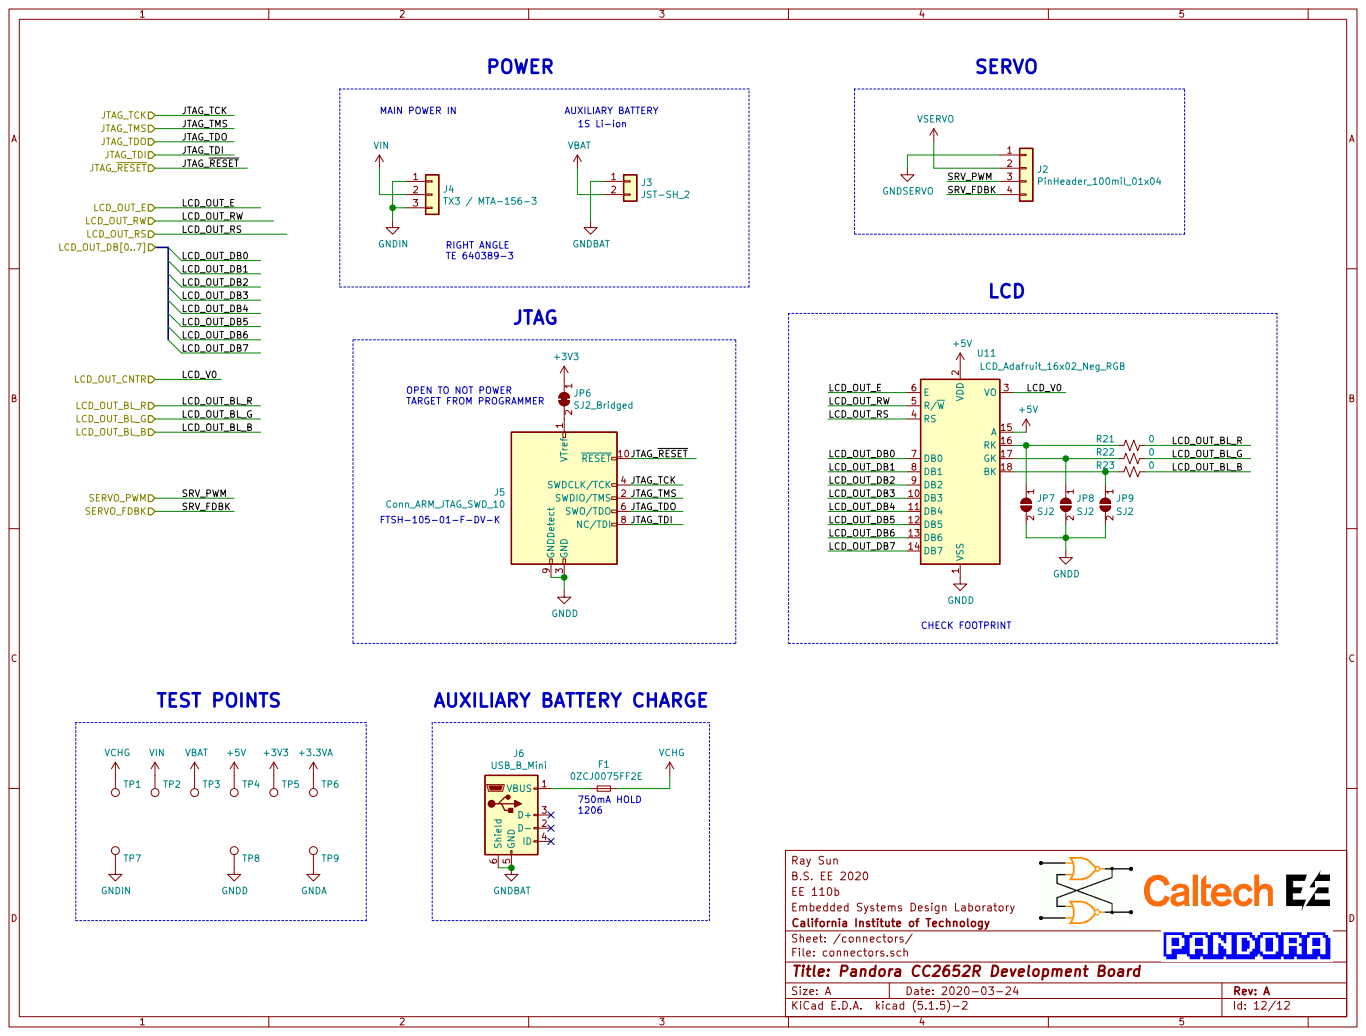
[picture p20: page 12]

JTAG_TCK
1S Li-ion TEST POINTS

OPEN TO NOT POWER TARGET FROM PROGRAMMER

3 SWDCLK/TCK 4 SWO/TDO 6 NC/TDI 8 GNDDetect 9

Embedded Systems Design Laboratory EE 110b B.S. EE 2020 Ray Sun

File: connectors.sch Sheet: /connectors/ California Institute of Technology

Id: 12/12 Title: Pandora CC2652R Development Board









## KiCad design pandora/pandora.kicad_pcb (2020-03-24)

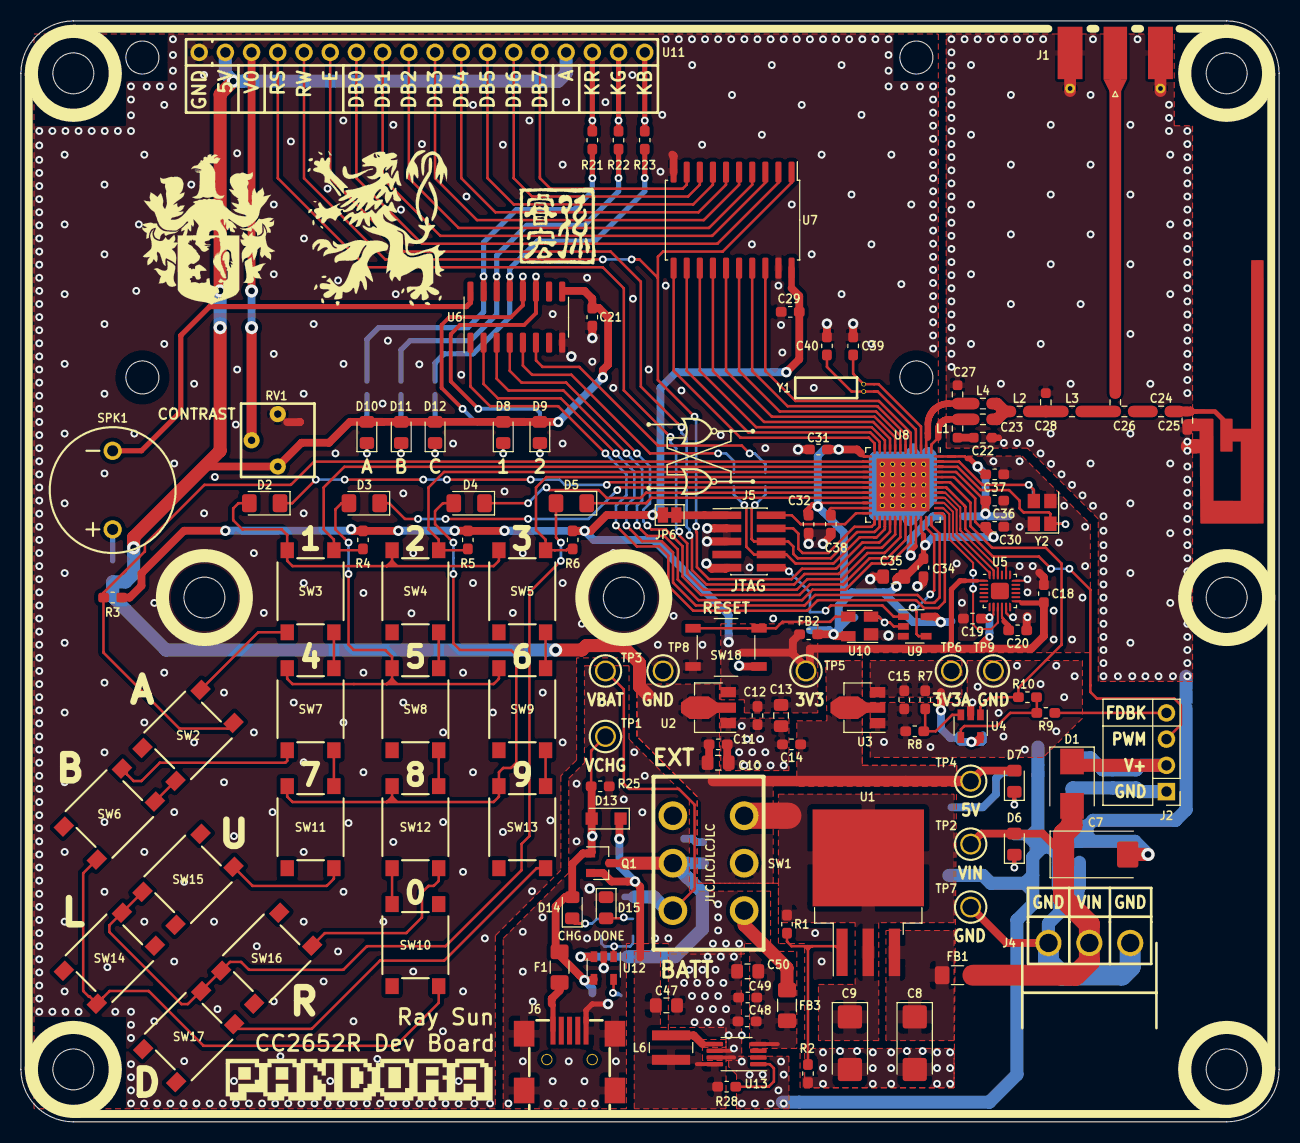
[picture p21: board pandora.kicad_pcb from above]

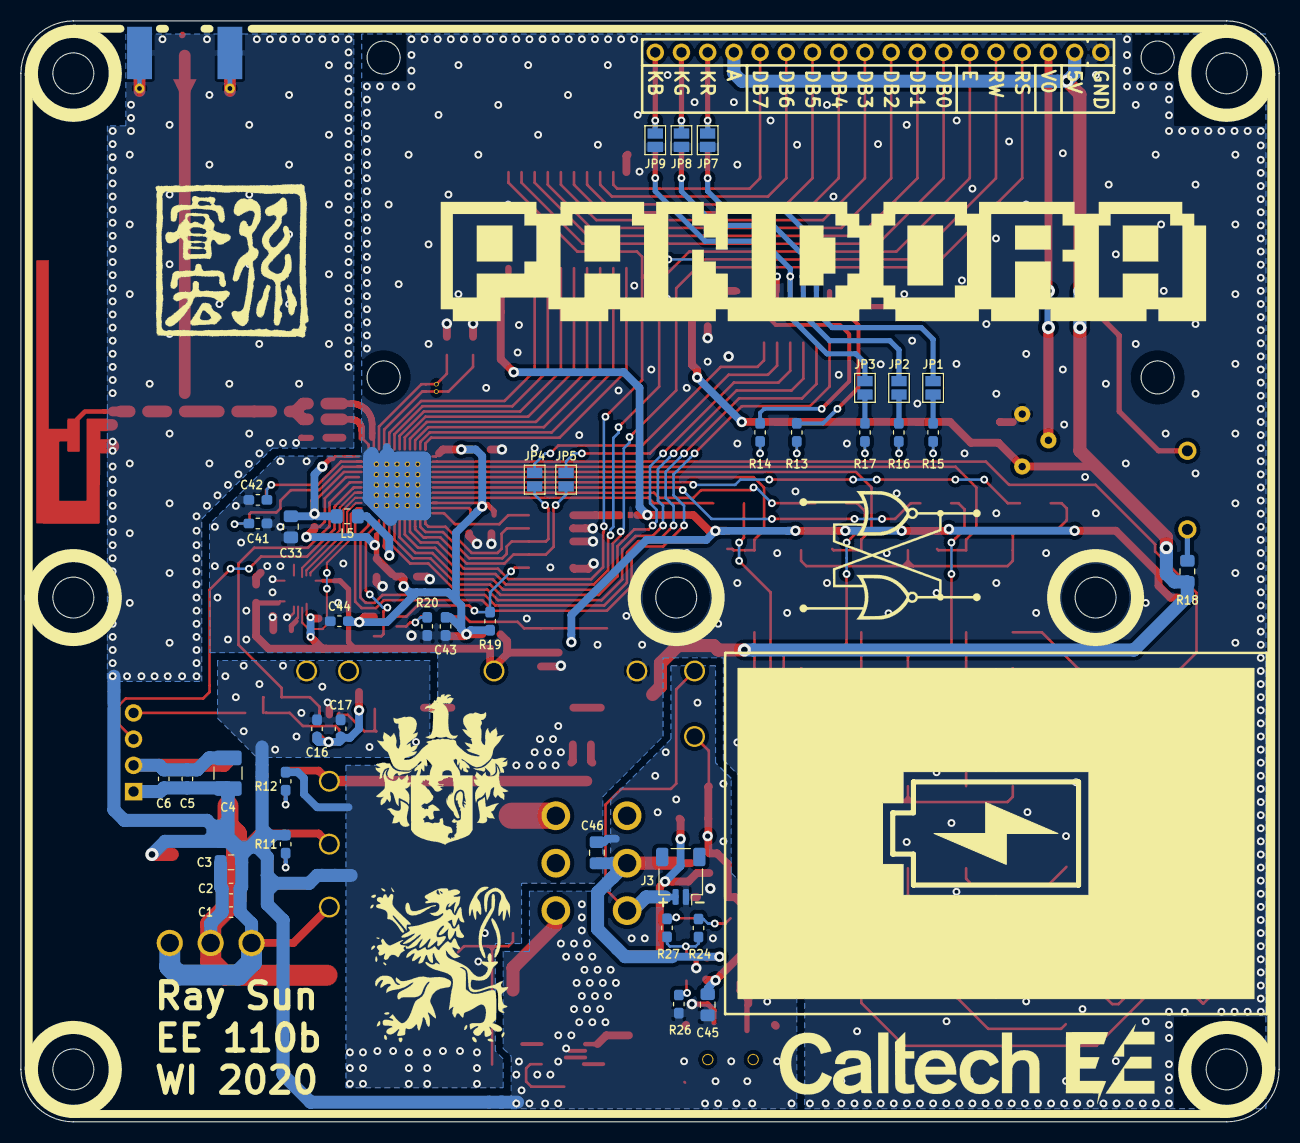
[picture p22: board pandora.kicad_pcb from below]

Board: 2 copper layers, 121.9 x 106.7 mm, 176 parts (43 on the bottom side), 121 nets.

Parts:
AE1: SWRU120D; Texas_SWRU120D_InvF_2.4GHz_Left
C1, C6, C16, C19, C20, C21, C29, C30, C31, C32, C34, C36, C37, C43, C44, C48: 0.1uF; C_0603_1608Metric_Pad1.05x0.95mm_HandSolder
C2, C5, C11, C12, C14, C15, C17, C38, C49: 1uF; C_0603_1608Metric_Pad1.05x0.95mm_HandSolder
C3, C13, C50: 10uF; C_0805_2012Metric_Pad1.15x1.40mm_HandSolder
C4: 47uF; C_1210_3225Metric_Pad1.42x2.65mm_HandSolder
C7: 47uF; CP_EIA-7343-31_Kemet-D
C8, C9: 10uF; CP_EIA-6032-28_Kemet-C_Pad2.25x2.35mm_HandSolder
C10, C33, C35: 22uF; C_0805_2012Metric_Pad1.15x1.40mm_HandSolder
C18: 10nF; C_0603_1608Metric_Pad1.05x0.95mm_HandSolder
C22: 12pF; 0603
C23, C27, C28: 1pF; 0603
C24: 1.8pF; 0603
C25: DNP; 0603
C26: 12pF; 0603_Branch
C39, C40: 15pF; C_0603_1608Metric_Pad1.05x0.95mm_HandSolder
C41, C42: 12pF; C_0603_1608Metric_Pad1.05x0.95mm_HandSolder
C45, C46, C47: 4.7uF; C_0805_2012Metric_Pad1.15x1.40mm_HandSolder
D1: S3JBHR5G; D_SMB
D2, D3, D4, D5: 1N4148; D_1206_3216Metric_Pad1.42x1.75mm_HandSolder
D6, D10: RED; LED_0805_2012Metric_Pad1.15x1.40mm_HandSolder
D7, D11, D15: GREEN; LED_0805_2012Metric_Pad1.15x1.40mm_HandSolder
D8, D9, D12: BLUE; LED_0805_2012Metric_Pad1.15x1.40mm_HandSolder
D13: PMEG10020ELRX; D_SOD-123W
D14: ORANGE; LED_0805_2012Metric_Pad1.15x1.40mm_HandSolder
F1: 0ZCJ0075FF2E; Fuse_1206_3216Metric_Pad1.42x1.75mm_HandSolder
FB1, FB3: 1206_4A; L_1206_3216Metric_Pad1.42x1.75mm_HandSolder
FB2: 0603_500mA; L_0603_1608Metric_Pad1.05x0.95mm_HandSolder
H1, H2, H3, H4, H5, H6, H7: #6; MountingHole_No6
J1: SMA; SMA_Molex_73251-1153_EdgeMount_Horizontal
J2: PinHeader_100mil_01x04; PinHeader_1x04_P2.54mm_Vertical
J3: JST-SH_2; JST_SH_SM02B-SRSS-TB_1x02-1MP_P1.00mm_Horizontal
J4: TX3 / MTA-156-3; TE_640389-3
J5: Conn_ARM_JTAG_SWD_10; PinHeader_2x05_P1.27mm_Vertical_SMD_Long
J6: USB_B_Mini; USB_MiniB_KMBSMT5SS30
JP1, JP2, JP3, JP4, JP5, JP7, JP8, JP9: SJ2; SolderJumper-2_P1.3mm_Open_Pad1.0x1.5mm
JP6: SJ2_Bridged; SolderJumper-2_P1.3mm_Bridged_Pad1.0x1.5mm
L1, L4: 2.4nH; 0603
L2, L3: 2nH; 0603
L5: 6.8uH; L_0805_2012Metric_Pad1.15x1.40mm_HandSolder
L6: 4.7uH; L_Wuerth_MAPI-4020
NT1, NT2, NT3, NT4, NT5: Net-Tie_2; NetTie-2_SMD_50mil
Q1: DMP1045U; SOT-23
R1, R12: 1.2k; R_0603_1608Metric_Pad1.05x0.95mm_HandSolder
R2: 3.6k; R_0603_1608Metric_Pad1.05x0.95mm_HandSolder
R3, R4, R5, R6, R19, R25, R26, R28: 10k; R_0603_1608Metric_Pad1.05x0.95mm_HandSolder
R7, R9: 150k; R_0603_1608Metric_Pad1.05x0.95mm_HandSolder
R8: 160k; R_0603_1608Metric_Pad1.05x0.95mm_HandSolder
R10: 120k; R_0603_1608Metric_Pad1.05x0.95mm_HandSolder
R11: 3.3k; R_0603_1608Metric_Pad1.05x0.95mm_HandSolder
R13: 330; R_0603_1608Metric_Pad1.05x0.95mm_HandSolder
R14, R17: 390; R_0603_1608Metric_Pad1.05x0.95mm_HandSolder
R15: 680; R_0603_1608Metric_Pad1.05x0.95mm_HandSolder
R16: 560; R_0603_1608Metric_Pad1.05x0.95mm_HandSolder
R18: 10; R_0805_2012Metric_Pad1.15x1.40mm_HandSolder
R20: 100k; R_0603_1608Metric_Pad1.05x0.95mm_HandSolder
R21, R22, R23: 0; R_0603_1608Metric_Pad1.05x0.95mm_HandSolder
R24, R27: 1k; R_0603_1608Metric_Pad1.05x0.95mm_HandSolder
RV1: 10k; Pot_VR4_Small
SPK1: DBX-01PN
SW1: GF-126-0317
SW2, SW3, SW4, SW5, SW6, SW7, SW8, SW10, SW11, SW12: PTS645-S-H-50-SMTR92-LFS; SW_Push_PTS645_SMT
SW9, SW13: PTS645-S-M-43-SMTR92-LFS; SW_Push_PTS645_SMT
SW14, SW15, SW16, SW17: PTS645-S-K-50-SMTR92-LFS; SW_Push_PTS645_SMT
SW18: PTS526-S-K-15-SMTR92; SW_Push_PTS526
TP1, TP2, TP3, TP4, TP5, TP6, TP7, TP8, TP9: TestPoint; TestPoint_62-80mil
U1: LM1086CS-ADJ; TO-263-3_TabPin2
U2, U3: MCP1702T-3302; SOT-89-3
U4: MCP6001; SOT-23-5
U5: MPU-9250; MPU-9250_Wide
U6: ULN2003D; SOIC-16_3.9x9.9mm_P1.27mm
U7: 74LCX245; SOIC-20W_7.5x12.8mm_P1.27mm
U8: CC2652R; Texas_RGZ0048A_Wide
U9: 74LVC1G08; SOT-23-5
U10: ADM811ZARTZ; SOT-143
U11: LCD_Adafruit_16x02_Neg_RGB
U12: MCP73831-2-OT; SOT-23-5
U13: MCP1642D-50; MSOP-8_3x3mm_P0.65mm
Y1: NC26_32.768k; NC26H_Mirrored
Y2: FA-238_48M; Crystal_SMD_SeikoEpson_FA238-4Pin_3.2x2.5mm

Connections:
+3.3VA: C15.1, C16.1, C17.1, R7.1, TP6.1, U3.3, U4.5
+3V3: C12.1, C13.1, C18.1, C19.2, C29.2, FB2.2, JP6.1, R3.1, R4.1, R5.1, R6.1, TP5.1, U2.3, U5.1, U5.8, U5.13, U7.20
+5V: C10.1, C11.1, C14.1, C21.2, D7.2, D8.2, D9.2, D10.2, D11.2, D12.2, R18.2, RV1.1, SW1.2, TP4.1, U2.2, U3.2, U6.9, U11.2, U11.15
/battery/VLV: C47.1, D13.1, L6.1, Q1.2, R28.2, U13.8
/connectors/JTAG_TCK: J5.4, U8.25
/connectors/JTAG_TDI: J5.8, JP5.1, U8.27
/connectors/JTAG_TDO: J5.6, JP4.1, U8.26
/connectors/JTAG_TMS: J5.2, U8.24
/connectors/JTAG_~RESET: J5.10, R19.2, U9.1
/connectors/LCD_OUT_BL_B: JP3.2, R23.1, U6.13
/connectors/LCD_OUT_BL_G: JP2.2, R22.1, U6.14
/connectors/LCD_OUT_BL_R: JP1.2, R21.1, U6.15
/connectors/LCD_OUT_CNTR: RV1.2, U11.3
/connectors/LCD_OUT_DB0: U7.2, U11.7
/connectors/LCD_OUT_DB1: U7.3, U11.8
/connectors/LCD_OUT_DB2: U7.4, U11.9
/connectors/LCD_OUT_DB3: U7.5, U11.10
/connectors/LCD_OUT_DB4: U7.6, U11.11
/connectors/LCD_OUT_DB5: U7.7, U11.12
/connectors/LCD_OUT_DB6: U7.8, U11.13
/connectors/LCD_OUT_DB7: U7.9, U11.14
/connectors/LCD_OUT_RS: U8.30, U11.4
/connectors/LCD_OUT_RW: U7.1, U8.28, U11.5
/connectors/SERVO_PWM: J2.3, U8.42
/imu/IMU_MISO: U5.9, U8.38
/imu/IMU_MOSI: U5.24, U8.39
/imu/IMU_SCK: U5.23, U8.40
/imu/IMU_~CS: U5.22, U8.41
/keypad/KPD_IN1: R3.2, SW2.2, SW6.2, SW10.2, SW14.2, U8.14
/keypad/KPD_IN2: R4.2, SW3.2, SW7.2, SW11.2, SW15.2, U8.15
/keypad/KPD_IN3: R5.2, SW4.2, SW8.2, SW12.2, SW16.2, U8.16
/keypad/KPD_IN4: R6.2, SW5.2, SW9.2, SW13.2, SW17.2, U8.17
/keypad/KPD_OUT1: D2.1, U8.18
/keypad/KPD_OUT2: D3.1, U8.19
/keypad/KPD_OUT3: D4.1, U8.20
/keypad/KPD_OUT4: D5.1, U8.21
/lcd/LCD_DB0: U7.18, U8.5
/lcd/LCD_DB1: U7.17, U8.6
/lcd/LCD_DB2: U7.16, U8.7
/lcd/LCD_DB3: U7.15, U8.8
/lcd/LCD_DB4: U7.14, U8.9
/lcd/LCD_DB5: U7.13, U8.10
/lcd/LCD_DB6: U7.12, U8.11
/lcd/LCD_DB7: U7.11, U8.12
/lcd/LCD_E: U8.29, U11.6
/led_speaker/LCD_BL_B: U6.4, U8.31
/led_speaker/LCD_BL_G: U6.3, U8.32
/led_speaker/LCD_BL_R: U6.2, U8.36
/led_speaker/LED1: JP5.2, U6.5
/led_speaker/LED1_DRV: R13.2, U6.12
/led_speaker/LED2: JP4.2, U6.6
/led_speaker/LED2_DRV: R14.2, U6.11
/led_speaker/LEDA_DRV: JP1.1, R15.2
/led_speaker/LEDB_DRV: JP2.1, R16.2
/led_speaker/LEDC_DRV: JP3.1, R17.2
/led_speaker/SPEAKER: U6.1, U8.37
/led_speaker/SPK_DRV: SPK1.2, U6.16
/mcu/DCDC_SW: L5.1, U8.33
/mcu/RF_N: C27.1, L4.1, U8.2
/mcu/RF_P: C23.2, L1.2, U8.1
/mcu/VMCUA: C33.1, C36.2, C37.2, L5.2, U8.45, U8.48
/mcu/~RESET: U8.35, U9.4
/servo/AIN: R10.1, U4.1, U8.43
/servo/FDBK: J2.4, R9.2
/servo/VREF: R7.2, R8.1, U4.3
GNDA: C15.2, C16.2, C17.2, NT2.2, R8.2, TP9.1, U3.1, U4.2
GNDBAT: C45.2, C46.2, C47.2, C48.2, C49.2, C50.2, D15.1, J3.1, J6.5, J6.6, NT5.2, R25.1, R26.1, U12.2, U13.6, U13.7
GNDD: C8.2, C9.2, C10.2, C11.2, C12.2, C13.2, C14.2, C18.2, C19.1, C20.1, C21.1, C29.1, C30.1, C31.1, C32.1, C33.2, C34.1, C35.1, C36.1, C37.1, C38.1, C39.1, C40.2, C41.1, C42.2, C43.2, C44.1, J5.3, J5.5, J5.9, JP7.2, JP8.2, JP9.2, NT1.2, R2.2, R12.2, R20.2, RV1.3, SW18.1, TP8.1, U2.1, U5.11, U5.18, U5.20, U6.8, U7.10, U7.19, U8.49, U9.3, U10.1, U11.1, Y2.2, Y2.4
GNDIN: C1.2, C2.2, C3.2, C7.2, J4.1, J4.3, NT1.1, NT2.1, NT3.1, NT4.1, NT5.1, R11.2, TP7.1
GNDRF: AE1.2, C22.1, C25.2, C27.2, C28.2, J1.2, NT3.2
GNDSERVO: C4.2, C5.2, C6.2, J2.1, NT4.2
unnamed: AE1.1, C24.1, C25.1
unnamed: C8.1, FB1.1, U1.3
unnamed: C9.1, R1.1, SW1.1, U1.2
unnamed: C20.2, U5.10
unnamed: C22.2, L1.1
unnamed: C23.1, L2.1, L4.2
unnamed: C24.2, C26.2
unnamed: C26.1, L3.2
unnamed: C26.3, J1.1
unnamed: C28.1, L2.2, L3.1
unnamed: C38.2, U8.23
unnamed: C39.2, U8.3, Y1.1
unnamed: C40.1, U8.4, Y1.2
unnamed: C41.2, U8.46, Y2.1
unnamed: C42.1, U8.47, Y2.3
unnamed: C46.1, Q1.3, SW1.5, U12.3
unnamed: C48.1, C49.1, C50.1, FB3.2, U13.4
unnamed: D2.2, SW2.1, SW3.1, SW4.1, SW5.1
unnamed: D3.2, SW6.1, SW7.1, SW8.1, SW9.1
unnamed: D4.2, SW10.1, SW11.1, SW12.1, SW13.1
unnamed: D5.2, SW14.1, SW15.1, SW16.1, SW17.1
unnamed: D6.1, R11.1
unnamed: D7.1, R12.1
unnamed: D8.1, R13.1
unnamed: D9.1, R14.1
unnamed: D10.1, R15.1
unnamed: D11.1, R16.1
unnamed: D12.1, R17.1
unnamed: D14.1, R24.1
unnamed: D15.2, R27.1
unnamed: F1.1, J6.1
unnamed: J5.1, JP6.2
unnamed: JP7.1, R21.2, U11.16
unnamed: JP8.1, R22.2, U11.17
unnamed: JP9.1, R23.2, U11.18
unnamed: L6.2, U13.5
unnamed: R1.2, R2.1, U1.1
unnamed: R9.1, R10.2, U4.4
unnamed: R18.1, SPK1.1
unnamed: R20.1, U9.2, U10.2
unnamed: R24.2, R27.2, U12.1
unnamed: R26.2, U12.5
unnamed: R28.1, U13.1
unnamed: SW18.2, U10.3
VBAT: J3.2, SW1.6, TP3.1
VBOOST: FB3.1, SW1.3
VCHG: C45.1, D13.2, D14.2, F1.2, Q1.1, R25.2, TP1.1, U12.4
VIN: C1.1, C2.1, C3.1, C7.1, D1.2, D6.2, FB1.2, J4.2, TP2.1
VMCU: C30.2, C31.2, C32.2, C34.2, C35.2, C43.1, C44.2, FB2.1, R19.1, U8.13, U8.22, U8.34, U8.44, U9.5, U10.4
VSERVO: C4.1, C5.1, C6.1, D1.1, J2.2

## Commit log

2020-01-17 Make project
    [pandora.kicad_pcb, pandora.sch]
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2020-01-17 Start schematic
    [pandora.sch]
2020-01-25 Create subsheets
    [connectors.sch, keypad.sch, lcd.sch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]
2020-01-25 Begin laying out hierarchial connections
    [connectors.sch, lcd.sch, mcu.sch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]
2020-01-27 Add IMU pins
    [connectors.sch, imu.sch, keypad.sch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]
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2020-01-30 Lay out servo and IMU
    [connectors.sch, imu.sch, keypad.sch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]
2020-01-31 Add battery holder symbols
    [power.sch]
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2020-01-31 Redesign reset circuit
    [mcu.sch]
2020-02-01 Revise to use Adafruit negative backlight LCD with ULN2003 driver
    [connectors.sch, imu.sch, keypad.sch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]
2020-02-01 Expose LCD contrast on separate label
    [connectors.sch, imu.sch, keypad.sch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]
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2020-02-01 Add LCD and connectors
    [connectors.sch, lcd.sch, mcu.sch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]
2020-02-01 Fix keypad diode direction
    [connectors.sch, imu.sch, keypad.sch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]
2020-02-01 Add resistor to prevent contention between JTAG reset and supervisor
    [mcu.sch, servo.sch]
2020-02-02 Fix pinout and add auxiliary LEDs to TDI/TDO
    [connectors.sch, imu.sch, keypad.sch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]
2020-02-02 Find servo amp resistor values
    [servo.sch]
2020-02-03 Power LCD level shifter from 3V3
    [connectors.sch, imu.sch, keypad.sch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]
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2020-02-04 Remove LCD holes from mechanical
    [connectors.sch, imu.sch, keypad.sch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]
2020-02-04 Add solder jumpers to select between backlight PWM and ground
    [led_speaker.sch]
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2020-02-06 Add solder jumpers to disconnect or select RGB backlight output
    [connectors.sch, imu.sch, keypad.sch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]
2020-02-07 Change speaker resistr to 1206
    [led_speaker.sch]
2020-02-07 Connect power switch properly
    [power.sch]
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2020-02-07 Begin redesigning reset circuit
    [mcu.sch]
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2020-02-07 Edit battery holder / switch package fields
    [power.sch]
2020-02-07 Change 10uF bulk caps to 22uF
    [mcu.sch, power.sch]
2020-02-07 Change some capacitors to take advantage of in house sizes
    [led_speaker.sch, power.sch]
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2020-02-07 Add logo to top level sheet
    [pandora.sch]
2020-02-07 Design reset supervisor
    [mcu.sch]
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2020-02-08 Add page layout description file
    [pandora.sch]
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2020-02-09 Fix VDDR, VDDRF as power input pins
2020-02-09 Annotate schematic; need to reconnect without heterogeneous busses
    [connectors.sch, imu.sch, keypad.sch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]
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2020-02-09 Redesign hierarchial interconnections
    [connectors.sch, imu.sch, keypad.sch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]
2020-02-09 Pass ERC without errors
    [pandora.sch]
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2020-02-09 Design battery charger circuit (need connector)
    [connectors.sch, imu.sch, keypad.sch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]
2020-02-09 Fix load share
    [power.sch]
2020-02-10 Add USB connector for charging
    [connectors.sch, power.sch]
2020-02-10 Design new boost converter
    [power.sch]
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2020-02-10 Annotate and regenerate docs
    [bom.csv, connectors.sch, imu.sch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]
2020-02-10 Consider not needing boost converter bypass
    [connectors.sch, imu.sch, keypad.sch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]
2020-02-10 Remove incorrect bypass disable
    [connectors.sch, imu.sch, keypad.sch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]
2020-02-10 Fuse charging input and remove alternative aux battery conector
    [connectors.sch]
2020-02-11 Remove ferrite beads from ground paths
    [connectors.sch, imu.sch, keypad.sch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]
2020-02-11 Remove bypass feature and add extra caps to boost output to help stability
    [connectors.sch, imu.sch, keypad.sch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]
2020-02-11 Change values on load share circuit
    [power.sch]
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2020-02-11 Add auxiliary battery switch
    [connectors.sch, imu.sch, keypad.sch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]
2020-02-11 Spec boost inductor (Wuerth MAPI)
    [power.sch]
2020-02-11 Update reset supervisor footprint
    [mcu.sch]
2020-02-11 Make NC26 crystal footprint
    [mcu.sch]
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2020-02-11 Fix servo pin header order
    [connectors.sch]
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2020-02-11 Update some symbol fields
    [keypad.sch, power.sch]
2020-02-11 Add supplier fields to symbols
    [connectors.sch, imu.sch, keypad.sch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]
2020-02-12 Find switch part numbers
    [keypad.sch, mcu.sch]
2020-02-12 Rename button footprints and select reset button
    [keypad.sch, mcu.sch]
2020-02-12 Reannotate by Y position for more sensible keypad
    [connectors.sch, imu.sch, keypad.sch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]
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2020-02-12 Spec MCU analog power filter inductor
    [mcu.sch]
2020-02-12 Add auxiliary LEDs to backlight lines with jumpers
    [connectors.sch, imu.sch, keypad.sch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]
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2020-02-13 Pick correct battery connector
    [connectors.sch, power.sch]
2020-02-13 Make right angle MTA-156 footprint (need to verify)
    [connectors.sch]
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2020-02-13 Update 0402 ffootprint ields
    [mcu.sch, pandora.sch, rf.sch]
2020-02-13 Make long JTAG header footprint
    [connectors.sch]
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2020-02-18 Redesign LED jumpers to cut down on components
    [connectors.sch, lcd.sch, led_speaker.sch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]
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2020-02-18 Reorganize power into two sheets
    [battery.sch, connectors.sch, imu.sch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]
2020-02-19 Add VBOOST power port
    [battery.sch, power.sch]
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2020-02-19 Update footprints on schematic
    [connectors.sch, imu.sch, servo.sch]
2020-02-19 Correct 22uF ceramic sizes to 0805
    [battery.sch, connectors.sch, imu.sch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]
2020-02-25 Change 1N4148 footprint to 1206
    [battery.sch, connectors.sch, imu.sch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]
2020-02-26 Change servo drop diode to SMD package (SMB)
    [power.sch]
2020-02-27 Spec DPDT switch and FBs
    [battery.sch, connectors.sch, imu.sch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]
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2020-02-28 Continue layout (CPWG width needs to be defined)
    [mcu.sch, pandora.kicad_pcb]
2020-03-02 Replace speaker resistor with 0805
    [battery.sch, connectors.sch, imu.sch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]
2020-03-02 Make #6 mounting holes
    [mechanical.sch, pandora.kicad_pcb]
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2020-03-06 Generate preliminary Gerbers and BOM
    [bom.csv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]
2020-03-07 Fix top silk
    [pandora.kicad_pcb]
2020-03-07 Fix bottom silk
    [pandora.kicad_pcb]
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2020-03-07 Make schematic size ANSI A
    [battery.sch, connectors.sch, imu.sch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]
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2020-03-08 Replace RF components with 0603
    [battery.sch, connectors.sch, imu.sch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]
2020-03-08 Make square 0603 footprint
    [rf.sch]
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2020-03-08 Stitch RF plane and decorate
    [pandora.kicad_pcb]
2020-03-08 Fix planes
    [pandora.kicad_pcb]
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2020-03-09 Fix silkscreen
    [pandora-B_Cu.gbl, pandora-B_Mask.gbs, pandora-B_SilkS.gbo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]
2020-03-09 Fix FA-238 and 10uF tant footprints
    [mcu.sch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]
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2020-03-09 Fix MCP1702 pinout
    [pandora-B_Cu.gbl, pandora-B_Mask.gbs, pandora-B_SilkS.gbo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]
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2020-03-09 Fix some FreeDFM issues
    [pandora-B_Cu.gbl, pandora-B_Mask.gbs, pandora-B_SilkS.gbo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]
2020-03-09 Fix RF top ground zone
    [pandora-B_Cu.gbl, pandora-B_Mask.gbs, pandora-B_SilkS.gbo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]
2020-03-09 Add local 3D models and make small aesthetical changes
    [pandora-B_Cu.gbl, pandora-B_Mask.gbs, pandora-B_SilkS.gbo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]
2020-03-11 Generate Gerbers without NO ADDITIONAL COPPER on edge layer
    [pandora-B_Cu.gbl, pandora-B_Mask.gbs, pandora-B_SilkS.gbo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]
2020-03-21 Clean up analog trace and ground spacing
    [pandora-B_Cu.gbl, pandora-B_Mask.gbs, pandora-B_SilkS.gbo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]
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2020-03-21 Actually use wider VQFN footprints
    [imu.sch, mcu.sch, pandora.kicad_pcb]
2020-03-21 Replace pot with THT one, and add aesthetics
    [lcd.sch, pandora.kicad_pcb]
2020-03-21 Regenerate Gerbers and BOM
    [bom.csv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]
2020-03-24 Move R25 to top to avoid battery connector and move designators around
    [pandora.kicad_pcb, power.sch]
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2020-03-24 Fix reset button on schematic
    [mcu.sch]
